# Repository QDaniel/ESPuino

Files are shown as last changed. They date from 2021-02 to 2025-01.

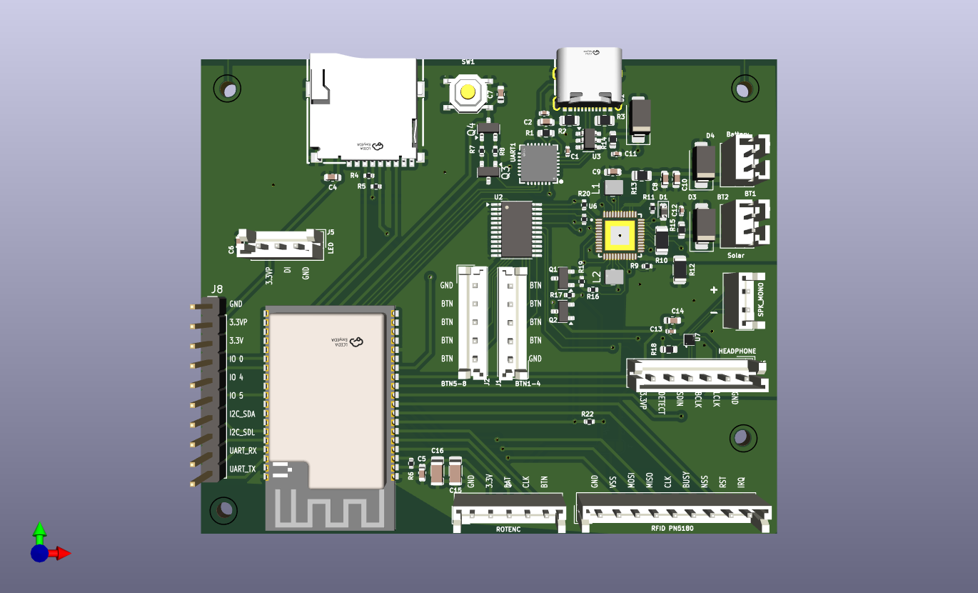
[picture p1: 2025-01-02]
PCBs/QUinoComplete/QUinoComplete_FG.png

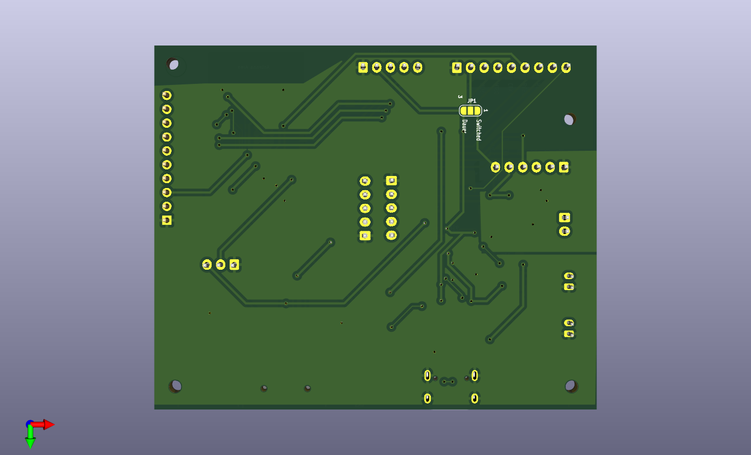
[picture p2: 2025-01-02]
PCBs/QUinoComplete/QUinoComplete_BG.png

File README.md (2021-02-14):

# ESPuino - rfid-based musiccontroller based on ESP32 with I2S-DAC-support

## NEWS
* As the creator of TonUINO claims it's trademark right, my project has been renamed to ESPuino. I'm totally respecting this and have to admit that I've been not aware of that. However, I instantly renamed everything and hopefully I didn't forget any parts. Since my repository has moved, please make sure (at least if you're using git) to change the URL of your local repository. An explanation was kindly [written by user](https://github.com/biologist79/ESPuino/issues/81).
* Please note: inline with the renaming of the project, MQTT-topics were changed as well as they've been including the old name. Please make sure to change your local MQTT-configuration as well. Sorry to [those](https://github.com/biologist79/ESPuino/issues/83) that spent time on this to point out.
* EN: I've set up a primarily German-speaking community with much documentation. Also an international corner for non-German-speakers is available at https://forum.espuino.de. Github-Login can be used there but it's not necessary.
* DE: Ich habe ein primär deutschsprachiges Forum aufgesetzt, welches ich mit reichlich Doku versehen habe. Würde mich freuen, euch dort zu sehen: https://forum.espuino.de. Ihr könnt euch dort mit eurem Github-Login einloggen, jedoch auch "normal" anmelden.
## Changelog
Moved to [another location](changelog.md) as it became to prominent here. Only last three events are kept:
* 01.02.2020: Introducing PCB: Lolin32 with SD_MMC + PN5180
* 06.02.2020: German umlauts now supported. When uploading via FTP make sure to change charset to CP437.
* 09.02.2020: Added support for bluetooth-sink (a2dp). Thanks @grch87 & @elmar-ops for providing this feature! Please note: wifi not available is now coloured green as blue make totally sense for bluetooth :-)
## Known bugs
* Some webstreams don't run. Guess it's a combination of saturated connection-pool and lack of heap-memory. Works probably better if ESP32-WROVER (e.g. Lolin D32 pro) is used, as this chip has PSRAM. Advice: Don't enable modules (e.g. MQTT) if you don't need them as this could save memory (and trouble).
* English translation for webgui is currently outdated. This will be fixed soon when i18n-support will be integrated.
## ESPuino - what's that?
The basic idea of ESPuino is to provide a way, to use the Arduino-platform for a music-control-concept that supports locally stored music-files without DRM-restrictions. This basically means that RFID-tags are used to direct a music-player. Even for kids this concept is simple: place an RFID-object (card, character) on top of a box and the music starts to play. Place another RFID-object on it and anything else is played. Simple as that.

The core of my implementation is based on the popular [ESP32 by Espressif](https://www.espressif.com/en/products/hardware/esp32/overview). Having WiFi-support out-of-the-box makes it possible to provide further features like an integrated FTP-server (to feed the player with music), smarthome-integration via MQTT, webradio and administration via webgui. However, my primary focus was to port the project to a modular base. Said this mp3-decoding is done in software with a dedicated uSD-card-slot and music-output is done via I2S-protocol. I did all my tests on [Adafruit's MAX98357A](https://learn.adafruit.com/adafruit-max98357-i2s-class-d-mono-amp/pinouts), [UDA1334](https://www.adafruit.com/product/3678) and [headphone-pcb](https://github.com/biologist79/ESPuino/tree/master/PCBs/Headphone%20with%20PCM5102a%20and%20TDA1308). Hopefully, not only in theory, other DACs that support I2S can be used as well.

## Hardware-setup
The heart of my project is an ESP32 on a [Wemos Lolin32 development-board](https://www.ebay.de/itm/4MB-Flash-WEMOS-Lolin32-V1-0-0-WIFI-Bluetooth-Card-Based-ESP-32-ESP-WROOM-32/162716855489). If ordered in China (Aliexpress, eBay e.g.) it's pretty cheap (around 4€) but even in Europe it's only around 8€. Make sure to install the drivers for the USB/Serial-chip (CP2102 e.g.). But probably it's better to use it's successor (which has battery-measurement already included): [Wemos Lolin D32](https://de.aliexpress.com/item/32808551116.html). Or, if you're planning to hear webstreams regularly, [Wemos Lolin D32 pro](https://de.aliexpress.com/item/32883116057.html) might be a good decision. It comes with uSD-slot onboard and because of its ESP32-WROVER-B has PSRAM included. PSRAM is used as webstream-cache and might be used more intensively in future.
* [MAX98357A (like Adafruit's)](https://de.aliexpress.com/item/32999952454.html)
* [uSD-card-reader; 3.3V only; supports SPI + SD-MMC](https://www.ebay.de/itm/Micro-SPI-Kartenleser-Card-Reader-2GB-SD-8GB-SDHC-Card-3-3V-ESP8266-Arduino-NEU/333796577968) or [cheaper](https://de.aliexpress.com/item/4000899753727.html)
* [RFID-reader RC-522](https://www.amazon.de/AZDelivery-Reader-Arduino-Raspberry-gratis/dp/B074S8MRQ7)
* [RFID-reader PN5180](https://de.aliexpress.com/item/4001278551831.html)
* [RFID-tags](https://www.amazon.de/AZDelivery-Keycard-56MHz-Schlüsselkarte-Karte/dp/B07TVJPTM7)
* [Neopixel-ring](https://de.aliexpress.com/item/32673883645.html)
* [Rotary Encoder](https://de.aliexpress.com/item/33041814942.html)
* [Buttons](https://de.aliexpress.com/item/32896285438.html)
* [Speaker](https://www.visaton.de/de/produkte/chassiszubehoer/breitband-systeme/fr-7-4-ohm)
* uSD-card: doesn't have to be a super-fast one; µC is limiting the throughput. Tested 32GB without any problems.
* uSD in SD-MMC (1 Bit) mode: Several devkits with onboard SD slot have support for this mode, e.g.: (https://de.aliexpress.com/item/4001229463219.html)
* optional replace the RFID-reader with a the better one: PN5180 comes with better RFID-range, less power-consumption and support for ISO-15693 / iCode SLIX2 tags (https://www.bing.com/shop?q=pn5180&FORM=SHOPTB)

## Getting Started
* Arduino-IDE can be used but you need to satisfy dependencies for all the libraries listed in `platformio.ini` manually.
* Instead I recommend to install Microsoft's [Visual Studio Code](https://code.visualstudio.com/). This is a popular and powerful IDE that gives you the ability to install tons of (well-supported) plugins.
* Install [Platformio Plugin](https://platformio.org/install/ide?install=vscode) into [Visual Studio Code](https://code.visualstudio.com/) and make sure to have a look at the [documentation](https://docs.platformio.org/en/latest/integration/ide/pioide.html). Step-by-step-manual is available [here](https://randomnerdtutorials.com/vs-code-platformio-ide-esp32-esp8266-arduino/.)
* Install [Git](https://git-scm.com/downloads) and make a copy ("clone") my repository to your local computer using `git clone https://github.com/biologist79/ESPuino.git`. Using git you can keep your local repository easily up to date without doing copy'n'paste. To keep it up to date run `git pull origin master`. Further infos [here}(https://stackoverflow.com/questions/1443210/updating-a-local-repository-with-changes-from-a-github-repository).
* (Optional) Install [Gitlens](https://marketplace.visualstudio.com/items?itemName=eamodio.gitlens) as plugin (to have advanced Git-support).
* Now, that the git-repository is saved locally, import this folder into Platformio as a project.
* There's a file called `platformio.ini`, that contains the configuration for different develboards (e.g. env:lolin32). Platformio supports hundrets of boards out of the box. So probably you need to change/extend that configuration. Guess Lolin32 is described in platformio.ini but you need Lolin D32, then lookup Platformio's [documentation](https://docs.platformio.org/en/latest/boards/espressif32/lolin_d32.html) to know what to change.
* Depending on your operating system (Windows, Mac OS, Linux), you probably need to change `upload_port`and `monitor_port` as well.
* Edit `src/settings.h` according your needs. Especially don't forget to set `HAL` depending on your develboard.
* Edit board-specific (`HAL`) config-file (e.g. `settings-lolin32.h` for Lolin32 or `settings-lolin_d32.h` for Lolin D32). If you're running a board that is not listed there: start with `settings-custom.h` and change it according your needs.
* Connect your develboard via USB, click the alien-head to the left and run `Upload and Monitor`. All libraries necessary should be fetched in background now followed by code-compilation. After that, your ESP32 is flashed with the firmware. Depending on your develboard it might me necessary to push a button in order to allow ESP32 to enter flashmode (not necessary für Lolin32, D32 und D32 pro).
* Now have a look at the serial-output at the bottom of Visual Studio Code's windows. At the first run there might appear a few error-messages (related to missing entries in NVS). Don't worry, this is just normal. However, make sure SD is running as this is mandatory!
* If everything ran fine, at the first run, ESPuino should open an access-point with the name "ESPuino". Join this WiFi with your computer (or mobile) and enter `192.168.4.1` to your webbrowser. Enter WiFi-credentials and the hostname. After saving the configuraton, restart ESPuino. Hint: I tried to connect this access-point via Android mobile. Basically that's no problem, but as my mobile detected there'd be no internet-connection, it keept LTE-connection open and prevented me from connecting to `192.168.4.1`. So if in doubts use a computer.
* After reboot ESPuino tries to join your WiFi (with the credentials previously entered). If that was successful, an IP is shown in the serial-console of Visual Studio Code. You can call ESPuino's GUI using a webbrowser via this IP; make sure to allow Javascript. If mDNS-feature is active in `src/settings.h`, you can use the hostname configured extended by .local instead the IP. So if you configured `espuino` as hostname, you can use `espuino.local` for webgui and FTP.
* Via FTP you can upload data (but don't expect it to be super fast). It's round about 185 kb/s if SD is in SPI-mode and 310 kB/s if SD is in MMC-mode.
* FTP needs to be activated after boot by pressing `PAUSE` + `NEXT`-buttons (in parallel) first! Neopixel flashes green (1x) if enabling was successful. It'll be disabled automatically after next reboot. Means: you have to enable it every time you need it (if reboot was in between). Sounds annoying and maybe it is, but's running this way in order to have more heap-memory available (for webstream) if FTP isn't running.
* Via webbrowser you can configure various settings and pair RFID-tags with actions. If MQTT/FTP-support was not compiled, their config-tabs won't appear.

## Prerequisites / tipps
* Open settings.h
* choose if optional modules (e.g. MQTT, FTP, Neopixel) should be compiled/enabled
* For debugging-purposes serialDebug can be set to ERROR, NOTICE, INFO or DEBUG.
* If MQTT=yes, set the IP or hostname of the MQTT-server accordingly and check the MQTT-topics (states and commands)
* Advice: don't enable MQTT if there's no broker around because network-timeouts can really be a PITA.
* If Neopixel enabled: set NUM_LEDS to the LED-number of your Neopixel-ring and define the Neopixel-type using `#define CHIPSET`
* If you're using Arduino-IDE please make sure to change ESP32's partition-layout to `No OTA (2MB APP/2MB Spiffs)` as otherwise the sketch won't fit into the flash-memory.
* Open board-specific config-file and edit according your needs.
* If you want to monitor battery's voltage, make sure to enable `MEASURE_BATTERY_VOLTAGE`. Use a voltage-divider as voltage of a LiPo is way too high for ESP32 (only 3.3V supported!). For my tests I connected VBat with a serial connection of 130k + 130k resistors (VBat(+)--130k--X--130k--VBat(-)). X is the measure-point where to connect the GPIO to. If using Lolin D32 or Lolin D32 pro, make sure to leave both resistor-values unchanged at 100k. Same for GPIO: unchanged at 35.
Please note: via GUI upper and lower voltage cut-offs for visualisation of battery-voltage (Neopixel) is available. Additional GUI-configurable values are interval (in minutes) for checking battery voltage and the cut off-voltage below whose a warning is shown via Neopixel.
* If you're using a headphone-pcb with a [headphone jack](https://www.conrad.de/de/p/cliff-fcr1295-klinken-steckverbinder-3-5-mm-buchse-einbau-horizontal-polzahl-3-stereo-schwarz-1-st-705830.html) that has a pin to indicate if there's a plug, you can use this signal along with the feature `HEADPHONE_ADJUST_ENABLE` to limit the maximum headphone-voltage automatically. As per default you have to invert this signal (with a P-channel MOSFET) and connect it to GPIO22.
* Enabling `SHUTDOWN_IF_SD_BOOT_FAILS` is really recommended if you run your ESPuino in battery-mode without having a restart-button exposed to the outside of ESPuino's enclosure. Because otherwise there's no way to restart your ESPuino and the error-state will remain until battery is empty (or you open the enclosure, hehe).
* Enabling `PLAY_LAST_RFID_AFTER_REBOOT` will tell ESPuino to remember the last RFID-tag played after next reboot. So rebooting ESPuino will end up in autoplay. I don't really recommend this feature because if you use it along with a webstream, in case of streaming-issues this might end up in an infinite loop.

## SD-card: SPI or SD-MMC (1 bit)-mode?
Having SD working is mandatory. However, there are two modes available to access SD-cards: SPI and SD-MMC (1 bit).<br />
Advantages SD-MMC (1 bit) over SPI:
* Needs only three GPIOs (instead of four)
* It's faster. FTP-upload: 298 kiB vs 178 kiB. HTTP-upload: 372 kiB vs 184 kiB. (tested with filesize of 70.7 MiB.<br />
So why using SPI if SD-MMC seems to be better? The primary problem of SD-MMC is: you cannot choose different GPIOs. That doesn't sound bad but this can (depending on the uSD-card-reader-module) be a problem because maybe GPIO2 is pulled HIGH to 3.3V by a 10k-resistor. For example this is the case when using the reader-module named above in hardware-setup. It's a problem because if GPIO2 is pulled high at boot, ESP32 doesn't enter flash-mode. As soon as flash-mode is entered, it's no longer a problem. However, this behaviour can be an issue if ESP32 is deeply "burried" in ESPuino's enclosure and you want to update its firmware. But fortunately there's a way to bypass this problem: remove the [pullup-resistor shown in the picture](https://raw.githubusercontent.com/biologist79/ESPuino/master/pictures/Pullup-removal.jpg). It can be removed safely because if MMC-mode is set, pullup is done in software using `pinMode(2, INPUT_PULLUP);`. So it's not really a problem but you have to take note of that!

## RFID: RC522 or PN5180?
RC522 is so to say the Tonuino-standard. It's cheap and works, but RFID-tag has to be placed near the reader. PN5180 instead has better RFID range/sensitivity and can read ISO-15693 / iCode SLIX2-tags aka 'Tonies' (you need a password to read Tonies). You can also wake-up the board with the card. Disadvantages: is a bit more expensive and needs more GPIOs (6/7 instead of 4). Refer PN5180's wire-section below for further informations. Hint: if using 3.3V make sure to connect PN5180 to +5V AND 3.3V. Sounds weird but it's necessary.

## 3.3 or 5V?
* Why 3.3V? Because: if you plan to use battery-mode with a LiPo, there's no 5 V available (unless USB is connected).
That's why my design's focus is 3.3 V. If you want to use 5 V - do so, but be advised it's not compatible with LiPo-battery-mode. The Mosfet-circuit for saving power in deepsleep (see [Lolin32-schematics](https://github.com/biologist79/ESPuino/blob/master/PCBs/Wemos%20Lolin32/Pictures/Tonuino%20V2-Schematics.pdf) as reference) works as well for 5 V.
* MAX98357a: provides more power at 5 V but also runs at 3.3 V. Anyway: it's still loud enough (in my opinion).
* Neopixel: specification says it needs 5 V but also runs at 3.3 V.
* RC522: needs 3.3 V (don't power with 5 V!)
* PN5180: at 3.3 V make sure to connect both 5 V and 3.3 V-pins to 3.3 V.
* SD: needs 3.3 V but if voltage-regulator is onboard, it can be connected to 5 V as well
* Rotary encoder: 3.3 V (don't power with 5 V! Encoder doens't care if connected to 3.3 or 5 V, but GPIOs of ESP32 do!)

## Wiring (general)
Depending on the develboard you're using and the needs you have, there are different options available.
A lot of wiring is necessary to get ESPuino working. After my first experiments on a breadboard I soldered all the stuff onto a PCB in order to avoid wild-west-cabling. Especially for the interconnect between µC and uSD-card-reader make sure to use short wires (like 10cm or so)! As of my experience with a breadbord, male/male-connectors are better than female/female-connectors. Important: you can easily connect another I2S-DACs by just connecting them in parallel to the I2S-pins (DIN, BCLK, LRC). This is true for example if you plan to integrate a [line/headphone-pcb](https://www.adafruit.com/product/3678). In general, this runs fine. But unfortunately especially this board lacks of a headphone jack, that takes note if a plug is inserted or not. Best way is to use a [headphone jack](https://www.conrad.de/de/p/cliff-fcr1295-klinken-steckverbinder-3-5-mm-buchse-einbau-horizontal-polzahl-3-stereo-schwarz-1-st-705830.html) that has a pin that is pulled to GND, if there's no plug and vice versa. Using for example a MOSFET-circuit, this GND-signal can be inverted in a way, that MAX98357.SD is pulled down to GND if there's a plug. Doing that will mute MAX98537a and so turn off the speaker immediately if there's a plug and vice versa. Have a look at the PCB-folder in order to view the detailed solution. Here's an example for such a [headphone-pcb](https://github.com/biologist79/ESPuino/tree/master/PCBs/Headphone%20with%20PCM5102a%20and%20TDA1308) that makes use of GND.<br />
Have a look at the PCB-folder. I provided PCBs for a number of develboards. Probably this makes things easier for you.

## Wiring (2 SPI-instances: RC522 + SD)
Uses two SPI-instances. The first one for the RFID-reader and the second for SD-card-reader. This is also the [setup, I personally use](https://github.com/biologist79/ESPuino/tree/master/PCBs/Wemos%20Lolin32).<br />
| ESP32 (GPIO)  | Hardware | Pin | Comment |
| --- | --- | --- | --- |
| 3.3 (5) V | SD-reader | VCC | Connect to p-channel MOSFET for power-saving when µC is off  |
| GND | SD-reader | GND | |
| 15 | SD-reader | CS | |
| 13 | SD-reader | MOSI | |
| 16 | SD-reader | MISO | |
| 14 | SD-reader | SCK | |
| 3.3 V | RFID-reader | 3.3V | (Connect directly to GPIO 17 for power-saving when µC is off)  |
| GND | RFID-reader | GND | |
| 21 | RFID-reader | CS/SDA | |
| 23 | RFID-reader | MOSI | |
| 19 | RFID-reader | MISO | |
| 18 | RFID-reader | SCK | |
| 5 / 3.3 V | MAX98357 | VIN | Connect to p-channel MOSFET for power-saving when µC is off  |
| GND | MAX98357 | GND | |
| 25 | MAX98357 | DIN | |
| 27 | MAX98357 | BCLK | |
| 26 | MAX98357 | LRC | |
| --- | MAX98357 | SD | Info: if pulled down to GND amp will turn off |
| 34 | Rotary encoder | CLK | Change CLK with DT if you want to change the direction of RE |
| 35 | Rotary encoder | DT | Change CLK with DT if you want to change the direction of RE |
| 32 | Rotary encoder | BUTTON | |
| 3.3 V | Rotary encoder | + | |
| GND | Rotary encoder | GND | |
| 4 | Button (next) | | |
| GND | Button (next) | | |
| 2 | Button (previous) | | |
| GND | Button (previous) | | |
| 5 | Button (pause/play) | | |
| GND | Button (pause/play) | | |
| 3.3 V | Neopixel | V | Connect to p-channel MOSFET for power-saving when µC is off  |
| GND | Neopixel | G | |
| 12 | Neopixel | DI | |
| 17 | N-channel Mosfet | Gate | |
| 33 | Voltage-divider / BAT | | Optional: voltage-divider to monitor battery-voltage |
| 22 | Headphone jack | | Optional: if pulled to ground, headphone-volume is set |

Optionally, GPIO 17 can be used to drive a Mosfet-circuit in order to switch off peripherals (SD, Neopixel, RFID and MAX98357a) if ESP32 is in deepsleep. Please refer the schematics for my [Lolin32-PCB](https://github.com/biologist79/ESPuino/blob/master/PCBs/Wemos%20Lolin32/Pictures/Tonuino-Lolin32-Schematics.pdf) for further informations. If you need further informations on transistor-circuits visit this [website](https://dl6gl.de/schalten-mit-transistoren.html). <br />
In general I recommend using a [uSD-card-reader](https://www.ebay.de/itm/Micro-SPI-Kartenleser-Card-Reader-2GB-SD-8GB-SDHC-Card-3-3V-ESP8266-Arduino-NEU/333796577968) that can be run solely with 3.3V (doesn't have a voltage-regulator). This is because if 3.3V go through the voltage regulator a small voltage-drop will be introduced, which may lead to SD-malfunction as the resulting voltage is a bit too low. Vice versa if you want to connect your reader solely to 5V, make sure to have one WITH a voltage regulator :-). And by the way: when LiPo-battery is connected, there's no 5V. That's why I designed my [Lolin-PCBs](https://github.com/biologist79/ESPuino/tree/master/PCBs/Wemos%20Lolin32) with 3.3V only.

## Wiring (SD-card in 1 Bit SD-MMC mode) different to above
| ESP32 (GPIO)  | Hardware | Pin | Comment |
| --- | --- | --- | --- |
| -- | SD-reader | CS | no CS required |
| 15 | SD-reader | MOSI | |
| 2 | SD-reader | MISO | make sure there's no [hardware-pullup](https://raw.githubusercontent.com/biologist79/ESPuino/master/pictures/Pullup-removal.jpg) for MISO |
| 14 | SD-reader | SCK | |

Make sure to enable `SD_MMC_1BIT_MODE` if you want to use this feature. Don't(!) enable `SINGLE_SPI_ENABLE`. SD-MMC-mode requires these fixed PINs listed above. You can find a good comparison of different SD-card-modes here: (https://www.instructables.com/Select-SD-Interface-for-ESP32/).
Advice: Double check that above PINs are not used elsewhere (e.g. GPIO2 is used as PREVIOUS_BUTTON as per default in settings.h).

## Wiring (1 SPI-instance: RC522 + SD) [EXPERIMENTAL, maybe not working!]
Basically the same as using 2 SPI-instances but...
In this case RFID-reader + SD-reader share SPI's SCK, MISO and MOSI. But make sure to use different CS-pins. Have to admit I had some problems to get this running. Seems to be connected properly, but nothing happens when an RFID-tag is applied. Maybe anybody else wants to point out :-)

| ESP32 (GPIO)  | Hardware | Pin | Comment |
| --- | --- | --- | --- |
| 3.3 (5) V | SD-reader | VCC | Connect to p-channel MOSFET for power-saving when µC is off  |
| GND | SD-reader | GND | |
| 15 | SD-reader | CS | Don't share with RFID! |
| 3.3 V | RFID-reader | 3.3V | Connect directly to GPIO 17 for power-saving when µC is off  |
| GND | RFID-reader | GND | |
| 21 | RFID-reader | CS/SDA | Don't share with SD! |
| 23 | RFID+SD-reader | MOSI | |
| 19 | RFID+SD-reader | MISO | |
| 18 | RFID+SD-reader | SCK | |
| 5 / 3.3 V | MAX98357 | VIN | Connect to p-channel MOSFET for power-saving when µC is off  |
| GND | MAX98357 | GND | |
| 25 | MAX98357 | DIN | |
| 27 | MAX98357 | BCLK | |
| 26 | MAX98357 | LRC | |
| --- | MAX98357 | SD | Info: if pulled down to GND amp will turn off |
| 34 | Rotary encoder | CLK | Change CLK with DT if you want to change the direction of RE |
| 35 | Rotary encoder | DT | Change CLK with DT if you want to change the direction of RE |
| 32 | Rotary encoder | BUTTON | |
| 3.3 V | Rotary encoder | + | |
| GND | Rotary encoder | GND | |
| 4 | Button (next) | | |
| GND | Button (next) | | |
| 2 | Button (previous) | | |
| GND | Button (previous) | | |
| 5 | Button (pause/play) | | |
| GND | Button (pause/play) | | |
| 5 / 3.3 V | Neopixel | V | Connect to p-channel MOSFET for power-saving when µC is off  |
| GND | Neopixel | G | |
| 12 | Neopixel | DI | |
| 17 | N-channel Mosfet | Gate | |
| 33 | Voltage-divider / BAT | | Optional: voltage-divider to monitor battery-voltage |
| 22 | Headphone jack | | Optional: if pulled to ground, headphone-volume is set |

## Wiring (PN5180 instead of MFRC522) different to above
PN5180-reader needs at least two more GPIOs: RESET and BUSY. Double check pin-conflicts! `RFID_READER_TYPE_PN5180` needs to be enabled to use this feature. Make sure to disable `RFID_READER_TYPE_MFRC522` if doing so!
You can enable low power card-detection with `PN5180_ENABLE_LPCD`, but this needs another GPIO for IRQ. With low power card detection (LPCD) you can wake-up the ESP32 from deep-sleep just by applying a card to the reader. You need a PN5180-firmware >= 4.0. Most china-boards comes with older firmware. The latest firmware can be flashed with this [project](https://github.com/abidxraihan/PN5180_Updater_ESP32).

| ESP32 (GPIO)  | Hardware | Pin | Comment |
| --- | --- | --- | --- |
| 3.3 V | PN5180 RFID-reader | 3.3V | Connect directly to GPIO 17 for power-saving when µC is off |
| 3.3 V | | 3.3V | For low power card detection mode (LPCD) connect directly to 3.3V |
| 5 / 3.3 V | PN5180 RFID-reader | 5V | Don't forget to connect this pin the same way as 3.3V |
| GND | PN5180 RFID-reader | GND | |
| 21 | PN5180 RFID-reader | CS/SDA | Same as MFRC522. Don't share with SD! |
| 23 | PN5180 RFID-reader | MOSI | Same as MFRC522 |
| 19 | PN5180 RFID-reader | MISO | Same as MFRC522 |
| 18 | PN5180 RFID-reader | SCK | Same as MFRC522 |
| 16 | PN5180 RFID-reader | BUSY | be aware of SD MISO if running in SPI mode |
| 22 | PN5180 RFID-reader | RST | be aware of Headphone jack PIN |
| 39 | PN5180 RFID-reader | IRQ | optional, used for low power card detection (LPCD) |

## Wiring (custom) / different pinout
When using a develboard with SD-card-reader already integrated (Lolin D32 Pro, several TTGO-boards), the pinouts described above my not fit. Feel free to change them according your needs. Additionaly some boards may use one or some of the GPIOs I used for their internal purposes and that reason for are maybe not exposed via pin-headers. However, having them exposed doesn't mean they can be used without limits. This is because some GPIOs have to be logical LOW or HIGH at start/boot for example and this is probably not the case when connecting stuff to it. Feel free to adjust the GPIOs proposed by me (but be adviced it could take a while to get it running). If you encounter problems please refer the board's manual first. <br />
[Here](https://github.com/biologist79/ESPuino/tree/master/Hardware-Plaforms/ESP32-A1S-Audiokit) I described a solution for a board with many GPIOs used internally and a very limited number of GPIOs exposed. That's why I had to use different SPI-GPIOs for RFID as well. Please note I used a slightly modified [RFID-lib](https://github.com/biologist79/ESPuino/tree/master/Hardware-Plaforms/ESP32-A1S-Audiokit/lib/MFRC522) there. Please note: the code-basis is outdated. Will need to re-integrate it into my master-branch...

## WiFi
WiFi is mandatory for webgui, FTP and MQTT. However, WiFi can be temporarily or permanently disabled. There are two ways to do that:
* Use a special modification-card that can be configured via webgui
* Press previous-key (and keep it pressed) + press next-button in parallel shortly. Now release both.
This toggles the current WiFi-status: if it's currently enabled, it will be disabled instantly and vice versa. Please note: this WiFi-status will remain until you change it again, which means, that ESPuino will remember this state after the next reboot. Having Wifi enabled is indicated in idle-mode (no playlist active) with four *white* slow rotating LEDs whereas disabled WiFi is represented by those ones coloured *green*. Bluetooth-mode is indicated by *blue* LEDs.

## Bluetooth
ESPuino can be used as bluetooth-sink (a2dp). This mode can be enabled/disabled via a RFID-modification-card. Applying one will restart ESPuino immediately. Two modes are available which are toggled in between: "normal" and "bluetooth". Normal means: SD + WiFi are available whereas in mode "bluetooth" only bluetooth-support can be provided. If bluetooth is active, this is indicated by four slow rotating *blue* LEDs. Now you can stream to your ESPuino e.g. with your mobile device. Tested this with Android 8 and worked 100% flawless.
## After ESPuino is connected to your WiFi
After bringing ESPuino part of your LAN/WiFi, the 'regular' webgui is available at the IP assigned by your router (or the configured hostname). Using this GUI, you can configure:
* WiFi
* Binding between RFID-tag, file/directory/URL and playMode
* Binding between RFID-tag and a modification-type
* MQTT
* FTP
* Initial volume, maximum volume (speaker / headphone), brightness of Neopixel (nightmode / default) and inactivity-time

Webgui #1:


Webgui #2:


Webgui #3:


Webgui #4:


Webgui #5:


Webgui #6:


Webgui #7:


Webgui: websocket broken:


Webgui: action ok:


Please note: as you apply a RFID-tag to the RFID-reader, the corresponding ID is pushed to the GUI. So there's no need to enter such IDs manually (unless you want to). Filepath can be filled out by selecting a file/directory in the tree.
IMPORTANT: Every time you add, delete or rename stuff on the SD-card, it's necessary to rebuild the json-indexfile. Simply click on the refresh-button below the filetree and wait until it's done. This is because all operations of the filebrowser rely on this file in order to provide a fast way to access all the files and directories.

## Interacting with ESPuino
### Playmodes
It's not just simply playing music; different playmodes are supported:
* `single track` => plays one track one time
* `single track (loop)` => plays one track forever
* `audiobook `=> single file or playlist/folder; last play-position (file and playlist) is saved (when pushing pause or moving to another track) and re-used next time
* `audiobook` (loop) => same as audiobook but loops forever
* `folder/playlist (alph. sorted)` => plays all tracks in alph. order from a folder one time
* `folder/playlist (random order)` => plays all tracks in random order from a folder one time
* `folder/playlist (alph. sorted)` => plays all tracks in alph. order from a folder forever
* `folder/playlist (random order)` => plays all tracks in random order from a folder forever
* `webradio` => always only one "track": plays a webstream

### Modification RFID-tags
There are special RFID-tags, that don't start music by themself but can modify things. If applied a second time, it's previous action/modification will be reversed. Please note: all sleep-modes do dimming (Neopixel) automatically because it's supposed to be used in the evening when going to bed. Well, at least that's my children's indication :-) So first make sure to start the music then use a modification-card in order to apply your desired modification:
* lock/unlock all buttons
* sleep after 5/30/60/120 minutes
* sleep after end of current track
* sleep after end of playlist
* sleep after five tracks
* dimm neopixel
* current track in loop-mode (is "stronger" than playlist-loop but doesn't overwrite it!)
* playlist in loop-mode
* track und playlist loop-mode can both be activated at the same time, but unless track-loop isn't deactivated, playlist-loop won't be effective
* Toggle WiFi (enable/disable) => disabling WiFi while webstream is active will stop the webstream instantly!
* Toggle Bluetooth (enable/disable) => restarts ESPuino immediately

### Neopixel-ring (optional)
Indicates different things. Don't forget configuration of number of LEDs via #define NUM_LEDS
* While booting: every second LED (rotating orange)
* Unable to mount SD: LEDs flashing red (will remain forever unless SD-card is available or `SHUTDOWN_IF_SD_BOOT_FAILS` is active)
* IDLE: four LEDs slow rotating (white if WiFi enabled; green if WiFi disabled)
* BLUETOOTH: four LEDs slow rotating coloured blue
* ERROR: all LEDs flashing red (1x) if an action was not accepted
* OK: all LEDs flashing green (1x) if an action was accepted
* BUSY: violet; four fast rotating LEDs when generating a playlist. Duration depends on the number of files in your playlist.
* track-progress: rainbow; number of LEDs relative to play-progress
* playlist-progress: blue; appears only shortly in playlist-mode with the beginning every new track; number of LEDs relative to progress
* webstream: two slow rotating LEDs that change their colours rainbow-wise as the stream proceeds
* volume: green => red-gradient; number of LEDs relative from current to max volume
* switching off: red-circle that grows until long-press-time is reached
* buttons locked: track-progress-LEDs coloured red
* paused: track-progress-LEDs coloured orange
* rewind: if single-track-loop is activated a LED-rewind is performed when restarting the given track
* (Optional) Undervoltage: flashes three times red if battery-voltage is too low. This voltage-level can be configured via GUI.
* (Optional) Short press of rotary encoder's button provides battery-voltage visualisation via Neopixel. Upper und lower voltage cut-offs can be adjusted via GUI. So for example if lower voltage is set to 3.2 V and upper voltage to 4.2 V, 50% of the LEDs indicate a voltage of 3.7 V.

Please note: some Neopixels use a reversed addressing which leads to the 'problem', that all effects are shown
counter clockwise. If you want to change that behaviour, just enable `NEOPIXEL_REVERSE_ROTATION`.

### Buttons
Some buttons have different actions if pressed long or short. Minimum duration for long press in ms is defined by `intervalToLongPress`.
* previous (short): previous track / beginning of the first track if pressed while first track is playing
* previous (long): first track of playlist
* next (short): next track of playlist
* next (long): last track of playlist
* pause/play (short/long): pause/play
* rotary encoder (turning): vol +/-
* rotary encoder (button long): switch off (only when on)
* rotary encoder (button short): switch on (when switched off)
* rotary encoder (button short): show battery-voltage via Neopixel (when switched on and `MEASURE_BATTERY_VOLTAGE` is active)
* previous (long; keep pressed) + next (short) + release (both): toggle WiFi enabled/disabled

### Music-play
* Music starts to play right after a valid RFID-tag was applied
* If `PLAY_LAST_RFID_AFTER_REBOOT` is active, ESPuino will remember the last RFID applied => music-autoplay (if in doubts don't use this feature).
* If a folder should be played that contains many mp3s, the playlist generation can take a few seconds. Please note that a file's name including path cannot exceed 255 characters.
* While playlist is generated Neopixel indicates BUSY-mode.
* After last track was played, Neopixel indicates IDLE-mode.
* In audiobook-mode, last play-position is remembered (position in actual file and number of track, respectively) when a new track begins of if pause-button was hit.
* In webstream-mode the stream will instantly stop if WiFi-status is toggled to disabled. ESPuino will return to idle-mode and wait for new RFID-tag.

### Audiobook-mode
This mode is different from the other ones because the last playposition is saved. Playposition is saved when...
* next track starts.
* first/previous/last track requested by button.
* pause was pressed.
* playlist is over (playposition is set back to the first track and file-position 0).
* Please note: last playposition is not saved when applying a new RFID-tag. This is intended because otherwise you woldn't have a possibility to not save it.

### Webinterface-configuration
After having ESPuino running on your ESP32 in your local WiFi, the webinterface-configuration is accessable. Using this GUI you can configure:
* Wifi-configuration (Wifi-SSID, Wifi-password, ESPuino's name (for nameserver))
* Link between RFID-tag and corresponding action
* (optional) MQTT-configuration (broker's IP)
* (optional) FTP-configuration (username and password)
* General-configuration (volume (speaker + headphone), neopixel-brightness (night-mode + initial), sleep after inactivity)

### FTP (optional)
* FTP needs to be activated after boot by pressing `PAUSE` + `NEXT`-buttons (in parallel) first! Neopixel flashes green (1x) if enabling was successful. It'll be disabled automatically after next reboot. Means: you have to enable it every time you need it (if reboot was in between). Sounds annoying and maybe it is, but's running this way in order to have more heap-memory available (for webstream) if FTP isn't running.
* In order to avoid exposing uSD-card or disassembling ESPuino all the time for adding new music, it's possible to transfer music to the uSD-card using FTP.
* Default-user and password are set to `esp32` / `esp32` but can be changed later via GUI.
* Make sure to set the max. number of parallel connections to ONE in your FTP-client and the charset to CP437. CP437 is important if you want to use german umlauts (öäüß).
* Secured FTP is not available. So make sure to disable SSL/TLS.
* Software: my recommendation is [Filezilla](https://filezilla-project.org/) as it's free and available for multiple platforms.
* Don't expect a super fast data-transfer; it's around 185 kB/s (SPI-mode) and 310 kB/s (MMC-mode).
* Please note: if music is played in parallel, this rate decrases dramatically! So better stop playback when doing a FTP-transfer.

### Energy saving
As already described in the modify-section, there are different sleepmodes available. Additionaly µC will be put into deepsleep after 10 minutes of inactivity (configurable my maxInactivityTime) unless ESPuino doesn't play music, has a FTP-client connected and any input via buttons. Every button-interaction resets the counter.

### MQTT (optional)
Everything that can be controlled via RFID-tags and buttons, can also be controlled via MQTT (excepting toggling WiFi-status as this doesn't make sense). All manual interactions (buttons, RFID-tags) are also sent to MQTT in parallel, so everything is always in-sync (unless Wifi/MQTT-connection is broken). In my home-setup I'm using [openHAB](https://www.openhab.org/) to "encapsulate" MQTT into a nice GUI, that's accessible via APP + web. I [described](https://github.com/biologist79/ESPuino/tree/master/openHAB) a sample-config for openHAB2. However, meanwhile openHAb3 is available and all the stuff described can also be configured via GUI. Be advised that openHAB is pretty complex and you have to spend some time to get familiar with it.

### Supported file/stream-types
Please refer [ESP32-audioI2S](https://github.com/schreibfaul1/ESP32-audioI2S), as this is the library I used for music-decoding. Make sure to update especially this library regularly as it's development is still in progress.

### Backups
As all assignments between RFID-IDs and actions (playmode, file to play...) is saved in ESP's NVS, the problem is that it's all gone when the ESP is broken. So that's where a backup comes into play. So every time you change or add a new assignment between a RFID-tag and an action via GUI, a backup-file is saved on the uSD-card. The file's name can be changed via `backupFile`. So better don't delete it! Using the webgui you can use the upload-form to import such a file. To be honest: Sometimes I had some issues with Firefox doing this whereas Safari turned out to do it right. Don't know why :-(.

## Smarthome (optional)
As already described, MQTT is supported. In order to use it it's necessary to run a MQTT-broker; [Mosquitto](https://mosquitto.org/) for instance. After connecting to it, ESPuino subscribes to all command-topics. State-topics are used to push states to the broker in order to inform others if anything changed (change of volume, new playlist, new track... name it). Others, like openHAB, subscribe to state-topics end send commands via command-topics. So it's not just limited to openHAB. It's just necessary to use a platform, that supports MQTT. For further informations (and pictures) refer the [subfolder](https://github.com/biologist79/ESPuino/tree/master/openHAB).

## MQTT-topics and their ranges
Feel free to use your own smarthome-environments (instead of openHAB). The MQTT-topics available are described as follows. Please note: if you want to send a command to ESPuino, you have to use a cmnd-topic whereas ESPuino pushes its states back via state-topics. So guess you want to change the volume to 8 you have to send this number via topic-variable `topicLoudnessCmnd`. Immediately after doing to, ESPuino sends a conformation of this command using `topicLoudnessState`. To get hands on MQTT I recommend this [one](https://www.hivemq.com/mqtt-essentials/) as introducton (covers more than you need for ESPuino).

| topic-variable | range | meaning |
| --- | --- | --- |
| topicSleepCmnd | 0 or OFF | Power off ESPuino immediately |
| topicSleepState | ON or OFF | Sends ESPuino's current/last state |
| topicRfidCmnd | 12 digits | Set number of RFID-tag which 'emulates' an RFID-tag (e.g. `123789456089`) |
| topicRfidState | 12 digits | ID of current RFID-tag (if not a modification-card) |
| topicTrackState | String | Sends current track number, total number of tracks and full path of curren track. E.g. "(2/10) /mp3/kinderlieder/Ri ra rutsch.mp3" |
| topicTrackControlCmnd | 1 -> 7 | `1`=stop; `2`=unused!; `3`=play/pause; `4`=next; `5`=prev; `6`=first; `7`=last |
| topicLoudnessCmnd | 0 -> 21 | Set loudness (depends on minVolume / maxVolume) |
| topicLoudnessState | 0 -> 21 | Sends loudness (depends on minVolume / maxVolume |
| topicSleepTimerCmnd | EOP | Power off after end to playlist |
| | EOT | Power off after end of track |
| | EO5T | Power off after end of five tracks |
| | 1 -> 2^32 | Duration in minutes to power off |
| | 0 | Deactivate timer (if active) |
| topicSleepTimerState | various | Sends active timer (`EOP`, `EOT`, `EO5T`, `0`, ...) |
| topicState | Online, Offline | `Online` when powering on, `Offline` when powering off |
| topicCurrentIPv4IP | IPv4-string | Sends ESPuino's IP-address (e.g. `192.168.2.78`) |
| topicLockControlsCmnd | ON, OFF | Set if controls (buttons, rotary encoder) should be locked |
| topicLockControlsState  | ON, OFF | Sends if controls (buttons, rotary encoder) are locked |
| topicPlaymodeState | 0 - 10 | Sends current playmode (single track, audiobook...; see playmodes) |
| topicRepeatModeCmnd | 0 - 3 | Set repeat-mode: `0`=no; `1`=track; `2`=playlist; `3`=both |
| topicRepeatModeState | 0 - 3 | Sends repeat-mode |
| topicLedBrightnessCmnd  | 0 - 255 | Set brightness of Neopixel |
| topicLedBrightnessState | 0 - 255 | Sends brightness of Neopixel |
| topicBatteryVoltage | float | Voltage (e.g. 3.81) |

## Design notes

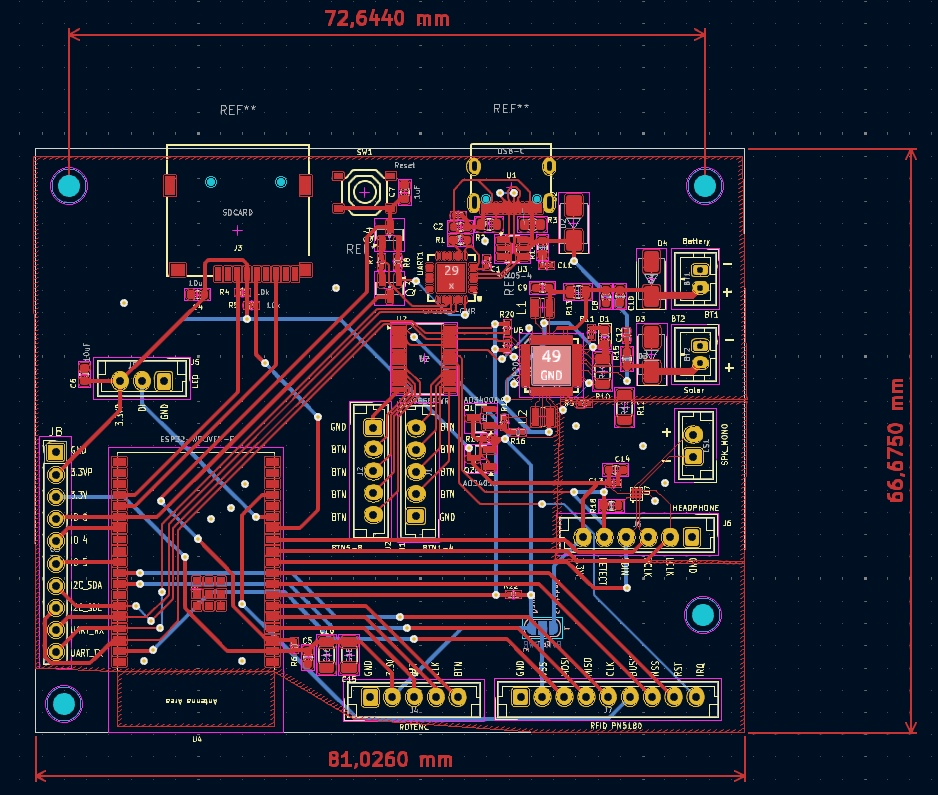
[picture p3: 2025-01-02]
PCBs/QUinoComplete/QUinoComplete_PL.png

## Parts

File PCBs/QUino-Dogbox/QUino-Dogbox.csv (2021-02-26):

Comment | Designator | Footprint | LCSC Part #
DW02S | BAT1 | JST_PH_B2B-PH-K_1x02_P2.00mm_Vertical
10uF/C0603 | C1 | C_0603_1608Metric_Pad1.08x0.95mm_HandSolder | C19702
27pF/50V/5%/C0G/C0402 | C2,C3 | C_0402_1005Metric_Pad0.74x0.62mm_HandSolder | C1555
22uF/6.3V/20%/X5R/C0603 | C4,C7,C9 | C_0603_1608Metric_Pad1.08x0.95mm_HandSolder | C59461
100nF/10V/10%/X7R/C0402 | C5,C6,C10 | C_0402_1005Metric_Pad0.74x0.62mm_HandSolder | C1525
1uF/10V/10%/X5R/C0402 | C8 | C_0402_1005Metric_Pad0.74x0.62mm_HandSolder | C52923
1N5819W/SOD123 | D1,D2,D3,D4,D6,D7,D8,D9 | D_SOD-123 | C402219
BAT54C(SOT23-3) | D5 | SOT-23_Handsoldering | C375703
WPM2015-3/TR | FET1 | SOT-23_Handsoldering | C213159
TP5000-QFN16 | IC1 | QFN65P400X400X90-17N-D | C51699
4.7u Inductor | L1 | L_1206_3216Metric | C1049
Q12MHz/20pF/10ppm/4P/3.2x2.5mm | Q1 | Crystal_SMD_3225-4Pin_3.2x2.5mm_HandSoldering | C9002
BC817-40(SOT23) | Q2,Q3 | SOT-23_Handsoldering | C181151
SI2302DS NMOS/GSD N-MOSFET transistor, gate/source/drain | Q4 | SOT-23_Handsoldering
QBC817 NPN/BEC NPN transistor, base/emitter/collector | Q5 | SOT-23_Handsoldering
10k/R0402 | R1,R2,R8,R9,R13,R16,R17,R18,R21 | R_0402_1005Metric_Pad0.72x0.64mm_HandSolder | C25744
220k/R0402 | R4 | R_0402_1005Metric_Pad0.72x0.64mm_HandSolder | C25767
470k/R0402 | R5,R10,R11 | R_0402_1005Metric_Pad0.72x0.64mm_HandSolder | C25790
2.2k/R0402 | R6,R7,R12,R14 | R_0402_1005Metric_Pad0.72x0.64mm_HandSolder | C25879
220/R0402 | R15 | R_0402_1005Metric_Pad0.72x0.64mm_HandSolder | C25091
0 /R0402 | R19 | R_0603_1608Metric_Pad0.98x0.95mm_HandSolder | C17168
4,7k/R0402 | R20 | R_0402_1005Metric_Pad0.72x0.64mm_HandSolder | C25900
IT-1185AU2-160G-G-TR | RST1 | SW_SPST_B3U-3000P
SW_DIP_x04 4x DIP Switch, Single Pole Single Throw (SPST) switch, small symbol | SW1 | DSHP04TSS | C319050
ESP32-WROVER | U1 | XCVR_ESP32-WROVER-I | C503591
CH340T(SSOP20W) | U3 | SSOP20-0.65-7.6X5.2MM | C8689
AMS1117-3.3 1A Low Dropout regulator, positive, 3.3V fixed output, SOT-223 | U4 | SOT-223-3_TabPin2 | C6186

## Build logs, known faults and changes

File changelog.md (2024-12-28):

# Changelog

## DEV-branch

* 27.12.2024: Fix audio dropouts in BT-Source mode
* 27.12.2024: ArduinoJson 7 (#357)
* 18.12.2024: Use saved SSID as LAST_SSID, when no successfull connection was possible #355, thanks to @nona00 !
* 18.12.2024: Check if #POWER defined, thanks to @QDaniel !
* 18.12.2024: Prepare for Arduino 3.1.0
* 16.12.2024: Add verbose log to indicate, that the restart is on purpose (#356), thanks to @thebino !
* 16.12.2024: LPCD: Only wake up if card is present in NVS (#352), thanks to @fox34 ! 
* 25.11.2024: Moving some settings to the Web UI (#350), thanks to @trainbird !
* 17.11.2024: Simplify 'SdCard_ParseM3UPlaylist' and fix parsing, thanks to @h4kun4m4t4t4 !
* 29.10.2024: Update Audio lib
* 29.10.2024: Enable CONFIG_ESP32_REV_MIN_3 to save some IRAM
* 22.10.2024: Cleaning up `management.html` (#348), thanks to @trainbird !
* 22.10.2024: Update Arduino-IRremote to support the ESP 3.0 core
* 29.09.2024: Removal of support for non-PSRAM HALs (Lolin32, LolinD32, DevkitC) and ESP32-A1S
* 29.09.2024: Prepare for Arduino 3.0.5
* 27.09.2024: PlatformIO package 6.9.0

## Version 2.3 (23.09.2024)

* 19.09.2024: Document the virtual cards in the UI #333, thanks to @caco3 !
* 18.09.2024: Re-designed tools page (#337), thanks to @caco3 !
* 16.09.2024: Fix sleep after playlist not toggling nightmode #336, thanks to @dneukirchen !
* 12.09.2024: PlatformIO package 6.8.1 (Arduino 2.0.17, ESP-IDF 4.4.7)
* 12.09.2024: Change default settings to match "ESPuino-mini 4Layer" board
* 11.09.2024: Fix string's expected length for rfid-cmnd via mqtt
* 11.09.2024: Ignore mqtt messages with length zero
* 10.09.2024: Porting to new web server library completed
* 09.06.2024: Consume about 50% less CPU time in Audio library
* 09.06.2024: Replace 3rd party library toastr (#331), thanks to @trainbird !
* 09.06.2024: Modernized webserver & optimized JSON delivery (#332)
* 20.05.2024: PlatformIO package 6.7.0 (Arduino 2.0.16, ESP-IDF 4.4.7)
* 20.05.2024: Disable bluetooth support for A1S (IRAM too small)
* 09.05.2024: Upgrade to Bootstrap v5.0 + Web-UI Enhancements (#328), thanks to @caco3 !
* 23.04.2024: Enhance UI minification (#323), thanks to @caco3 !
* 22.04.2024: Added virtual RFID-Cards (#319), thanks to @caco3 !
* 18.04.2024: Correct calculation of newFilePos for SEEK_POS_PERCENT, thanks to @sfields!
* 18.04.2024: Correct calculation of gPlayProperties.currentRelPos, thanks to @sfields!
* 18.04.2024: Get title from-VORBISCOMMENT and ID3, thanks to @sfields!
* 18.04.2024: Correct log for SSID name, thanks to @sfields!
* 18.04.2024: Add button to expand/shrink file list (#317), thanks to @caco3 !
* 18.04.2024: Fix remote UI debugging (#316), thanks to @caco3 !
* 14.04.2024: Embed swagger UI #314, thanks to @caco3 !
* 07.04.2024: Equalizer settings to WebUI #313, thanks to @trainbird !
* 28.03.2024: Audio lib, fix a memory leak with flac files
* 28.03.2024: Fix some warnings with upcoming Arduino 3 (ESP-IDF v5.1)
* 16.03.2024: Reduce memory usage by measurement of JSON payload length
* 15.03.2024: MQTT receive: Bug fix and avoid payload copy (#309), thanks to @eikel
* 15.03.2024: Add coverimage support for ogg, vorbis, opus (and some flac), thanks to @sfields !
* 19.02.2024: Add coverimage support for M4A files in Web-UI
* 18.02.2024: Add coverimage support for flac files in Web-UI, thanks to @sfields !
* 15.02.2024: Rework playlist generation (#275), thanks to @laszloh !
* 15.02.2024: Update sorting strings (#306), thanks to @freddy36 !
* 15.02.2024: Set title and navbar heading to hostname (#305), thanks to @freddy36 !
* 15.02.2024: Include mac address in info (#304), thanks to @freddy36 !
* 12.02.2024: Use natural sort (#296), thanks to @freddy36 !
* 09.02.2024: Remove explorerCreateParentDirectories (#301), thanks to @freddy36 !
* 08.02.2024: Remove convertFilenameToAscii (#298), Playlist fixes (#299), thanks to @freddy36 !
* 08.02.2024: Apple touch icon
* 07.02.2024: Fix dangling pointer in explorerHandleFileStorageTask (#297), thanks to @freddy36 !
* 07.02.2024: Reduce WiFi memory consumption (#295), thanks to @laszloh !
* 05.02.2024: Increase JSON buffer for /debug endpoint
* 02.02.2024: Improve progress calculation/indication, thanks to @freddy36 !
* 01.02.2024: Use NVS interator when reading RFID keys, save 4KB RAM , thanks to @laszloh !
* 01.02.2024: Use dynamically allocated buffer for file upload, save 32KB RAM , thanks to @laszloh !
* 30.01.2024: Add French Language (#292), thanks to @damda58 !
* 30.01.2024: Fix some audio dropouts with high-quality OPUS files
* 30.01.2024: Keep original mtime for gzip compressed files, avoiding uneccesary Web.o rebuilds (#293), thanks to @freddy36 !
* 23.01.2024: Updated documentation on LPCD setting, thanks to @derpicknicker1 !
* 21.01.2024: Build (tag 2.2) is broken when NEOPIXEL_ENABLE is not set #289, thanks to @RolinBert !
* 21.01.2024: PN5180: Save about 500 Bytes of RAM

## Version 2.2 (17.01.2024)

* 14.01.2024: Modify CMD_DIMM_LEDS_NIGHTMODE to toggle night light mode (#287), thanks to @laszloh !
* 11.01.2024: More free heap on boards with PSRAM (CONFIG_SPIRAM_MALLOC_ALWAYSINTERNAL)
* 10.01.2024: LPCD for ISO-15693 cards
* 05.01.2024: REST-API specification, thanks to @pauel !
* 02.01.2024: Partly revert: Fix webstream playlist abort when track fails (#285), thanks to @sfields !
* 02.01.2024: Show critical voltage slider only if SHUTDOWN_ON_BAT_CRITICAL defined
* 29.12.2023: Show station logo in Web-UI (if available)
* 29.12.2023: /rfid endpoint: List all assigned nvs entries (#280)
* 29.12.2023: Enhanced capabilities for task runtime debugging
* 28.12.2023: Bugfix 1: DONT_ACCEPT_SAME_RFID_TWICE_ENABLE and web frontend, thanks to @sfields !
* 28.12.2023: Add configuration for critical (shutoff) voltage in Web-UI, thanks to @SZenglein !
* 28.12.2023: New official PlatformIO package 6.5.0 (Arduino 2.0.14, ESP-IDF 4.4.6)
* 28.12.2023: Improve port expander handling (#283), thanks to @r-schmidt !
* 23.12.2023: Update audio library, avoid waiting in i2s_channel_write() to have more time in other tasks #636
* 22.12.2023: Web-UI: Preselection of root folder after load to avoid nasty warning when uploading files
* 17.12.2023: Update audio library, fixes click-noise seeking in file
* 13.12.2023: Immediately go to sleep if battery is critical (#274), thanks to @SZenglein !
* 12.12.2023: Long press behaviour, execute cmd directly after longpress-time (#279), thanks to @Joe91 !
* 12.12.2023: Fix false-positive error (Audio playback timeout)
* 10.12.2023: Distribute vTaskDelay() in main loop to avoid rare audio dropouts
* 10.12.2023: Fix wrong states on PE output pins (and SD-card failure on restart) #278, thanks to @36b6fp6s !
* 09.12.2023: Fix webstream playlist abort when track fails (#276), thanks to @laszloh !
* 07.12.2023: Show RC522 firmware version at startup, same as PN5180
* 04.12.2023: fix stuttering sound with some WAV & MP3 files, thanks to @wolle !
* 04.12.2023: change trackprogress communication from websocket to http to improve stability
* 04.12.2023: Remove some convertAsciiToUtf8() #272
* 30.11.2023: Fix a nullptr access after trying to replay an invalid filename (#271), thanks to Olaf!
* 29.11.2023: Updated audio library to play more MP3s, faster track change & delivery of the cover image
* 25.11.2023: Save some cpu time in audio task by only updating the playtime statistics every 250ms
* 22.11.2023: Web-UI: Search for files feature #268
* 21.11.2023: New command CMD_TOGGLE_MODE to switch Normal => BT-Sink => BT-Source
* 21.11.2023: Bugfix: Some commands e.g. Play/Pause did not work in BT-Source mode
* 21.11.2023: Faster pairing animation in BT-Source mode to better distinguish between the two BT modes
* 19.11.2023: Give audiotask a higher task priority, fixes crackling sound
* 19.11.2023: bugfix_same_rfid_twice init #262, see Github comments
* 17.11.2023: Show track progress, current playtime & duration in web-ui (#267)
* 16.11.2023: Fix delay with getLocalTime()
* 14.11.2023: Multi Wlan improvements (#266), thanks to @laszloh !
* 13.11.2023: Update third party libraries
* 08.11.2023: Fix HTML syntax errors, found with static code analysis tool "HtmlHint"
* 08.11.2023: Better logging for boards without PSRAM, fewer logs when compiling with NO_SDCARD
* 07.11.2023: Set timezone after startup, thanks to @Joe91 !

## Version 2.1 (07.11.2023)

* 04.11.2023: LPCD: wakeup check for ISO-14443 cards also with IRQ connected to port-expander
* 04.11.2023: Bugfix for showing wrong loglevel
* 03.11.2023: Web-ui: Fix overlapping info/log after pressing refresh button
* 01.11.2023: Fix folder upload with special chars & playtime formatting
* 31.10.2023: Code Formatting via clang-format #264, thanks to @laszloh & @fschrempf !!
* 27.10.2023: PlatformIO package 6.4.0, Arduino version stays at 2.0.11
* 26.10.2023: LPCD, RFID_IRQ on port-expander: fix compiler warning
* 26.10.2023: portTICK_RATE_MS is deprecated, use portTICK_PERIOD_MS instead (<https://github.com/espressif/esp-idf/issues/51>)
* 26.10.2023: Cppcheck: Fix some warnings/hints
* 22.10.2023: Bugfix PortExpander: beginTransmission()/endTransmission() must be balanced
* 21.10.2023: Enhanced logging: Show Loglevel
* 14.10.2023: New define NO_SDCARD, enable to start without any SD card, e.g. for a webplayer only.
* 05.10.2023: Enable "Arduino as component" by default
* 02.10.2023: Optimize Arduino as component (Disable BLE, BT-HFP & SPI ethernet)
* 25.09.2023: Handle unicode characters in NVS backup, write UTF-8 BOM in backup.txt
* 23.09.2023: Fix some log messages, update FTP & A2DP libraries
* 22.09.2023: Bugfix_same_rfid_twice init (#262) - Thanks to @Joe91 !!
* 06.09.2023: Arduino as component #261 - Thanks to @Joe91 !!
* 01.09.2023: Regression: start an initial WiFi scan on startup, fix redirect to captive portal
* 31.08.2023: Show nvs rfid assignments in web-ui & allow to delete single tags
* 31.08.2023: invoke "/rfid" endpoint (#260)
* 22.08.2023: Unify endpoints for accesspoint.html/management.html (#258)
* 15.08.2023: Web-ui: Change /restart endpoint to POST, refresh button for info & log modal
* 12.08.2023: Web-ui improvements
* 08.08.2023: check & avoid excessive "PING" calls from web-ui
* 08.08.2023: Configurable volumecurve #256, thanks to @Niko & @Wolle
* 08.08.2023: Refactor "/info" endpoint to make frontend/backend more independant #257
* 07.08.2023: LOG message for starting mDNS service
* 04.08.2023: Support for .oga audio files (Ogg Vorbis Audio container)
* 04.08.2023: Web-UI: Replace the template processor (#253)
* 02.08.2023: Bugfix M3U-playlist + PREVIOUSTRACK, thanks to @Niko!
* 31.07.2023: Restart system: avoid peripheral power down while restarting
* 31.07.2023: increase stacksize for audio-task (audio-streams with SSL)
* 22.07.2023: New command CMD_TELL_CURRENT_TIME for announcing the current time
* 21.07.2023: Show overall playtime total in web-ui
* 21.07.2023: Refactor shutdown procedure, add new command CMD_RESTARTSYSTEM
* 20.07.2023: Allow to configure the timezone in settings.h
* 19.07.2023: Show received timestamp of NTP request in log
* 11.07.2023: Fix regression, SD-card was not working in SPI mode
* 09.07.2023: New ftp server by peterus #254. Thanks to @Joe91 for contribution !!
* 08.07.2023: Allow to compile without SD-card (webplayer only)
* 04.07.2023: fix volume jumping at startup when initVolume <> factory default (3u)
* 29.06.2023: Update PN5180 library to fix compilation with DCORE_DEBUG_LEVEL=5
* 25.06.2023: Some spelling corrections, thanks to @SciLor !
* 23.06.2023: CMD_TELL_IP_ADDRESS: IP as text (replace thousand separator with word "point")
* 23.06.2023: web-upload improvement (#249). Thanks to @Joe91 !!
* 23.06.2023: Refactor web: Move dependant html-code from web.cpp to management.html (#250)
* 20.06.2023: PlatformIO package 6.3.2
* 20.06.2023: Move ScanWiFiOnStart to global WiFi configuration (#248)
* 18.06.2023: Stricter hostname validation (#246). Thanks to @SZenglein !!
* 18.06.2023: Some Web-UI improvements (#247)
* 17.06.2023: CMD_TOGGLE_WIFI_STATUS: Escape from BT-mode, WiFi cannot coexist with BT and can cause a crash
* 13.06.2023: Bluetooth configuration tab in web-interface (#244)
* 13.06.2023: Introduce new playmode "RANDOM_SUBDIRECTORY_OF_DIRECTORY_ALL_TRACKS_OF_DIR_RANDOM"
* 07.06.2023: Use bssid to connect to best WIFI and added option to always perform a WIFI-scan #241
* 06.06.2023: List available WiFi's in accesspoint view
* 06.06.2023: Remove support for Arduino 1.0.6 & playlist cache
* 05.06.2023: FastLED 3.6.0, PlatformIO package 6.3.1
* 01.06.2023: Improve neopixel display in Bluetooth speaker mode (BT-Sink) (#239)
* 01.06.2023: Reduce floating the log with redundant RSSI-messages: Log RSSI value only if it has changed by > 3 dBm
* 31.05.2023: Wifi: Log BSSID in scan and connection success, Wifi fixes (#240)
* 26.05.2023: Fix compiler warnings if MQTT_ENABLE is not defined
* 26.05.2023: Error in log: `[E][Preferences.cpp:96]` remove(): nvs_erase_key fail
* 23.05.2023: Migration from single-wifi setup: Initialize "use_static_ip"
* 22.05.2023: DEV branch has stricter compiler rules, fix some of (mostly harmless) warnings
* 22.05.2023: BTSource: fix Stack canary watchpoint triggered (BtAppT)
* 19.05.2023: Show Arduino version at startup & in web-info
* 19.05.2023: Add support for saving multiple wifi networks (#221)
* 09.05.2023: Bluetooth.cpp: Fix logging crash in sink mode (#238)
* 06.05.2023: README.md: Improve formatting, style, language and content
* 03.05.2023: Add support for control LEDs to be connected at the end of the NeoPixel Ring (#198)
* 27.04.2023: Remove usage of pgmspace.h header
* 27.04.2023: Move message formatting into LogMessages
* 26.04.2023: Configure button with active HIGH
* 20.04.2023: Speedup playlist generation & file listing by factor > 20
* 14.04.2023: Removing HAL for ESPmuse (stale development)
* 12.04.2023: Restrict value ranges to guard array access
* 11.04.2023: Merge pull request #226 from fschrempf/bugfix_rfid_assign
* 08.04.2023: Enforcing uniform codestyle
* 08.04.2023: Allow to escape from bluetooth mode with an unknown card, switch back to normal mode
* 03.04.2023: Merge pull request #223 from laszloh/bugfix/snprintf_warning, fix for snprintf trunctation warnings
* 03.04.2023: Add missing translations
* 31.03.2023: build.yml: Trigger workflow for all branches
* 27.03.2023: Merge pull request #219 from laszloh/feature/modern_cpp
* 25.03.2023: Transition to c++17
* 24.03.2023: Lost feature „PLAY_LAST_RFID_AFTER_REBOOT“
* 23.03.2023: Change volume animation to triggered mode
* 22.03.2023: Merge pull request #215 from fschrempf/execute-commands
* 22.03.2023: Change rotary encoder to delta mode
* 22.03.2023: Fix errorous indicator in case no audio is playing
* 22.03.2023: Fix for stuck LED-Shutdown animation
* 21.03.2023: Pause some tasks for speedup & smoother HTTP upload
* 21.03.2023: Feature: command-execution on control-site of webserver
* 21.03.2023: Merge pull request #210 from fschrempf/led_rework_cleaned_frieder
* 21.03.2023: Set default environment to arduino2 on dev-branch
* 18.03.2023: Bugfix: Corrupted files after HTTP-upload
* 18.03.2023: Major rework of LED animation task
* 13.03.2023: Fix for playing files via Web-UI for Arduino >=2.0.5
* 13.03.2023: Fix captive portal, Add fallback text AP setup
* 10.03.2023: Merge pull request #204 from laszloh/bugfix/heap_handling
* 10.03.2023: Always free playlist memory when SdCard_ReturnPlaylist is called
* 10.03.2023: Fix heap corruption due to insufficent memory allocation
* 10.03.2023: Harmonize return value of SdCard_ReturnPlaylist
* 10.03.2023: Correct the name of the "sort" function to randomize
* 10.03.2023: Create DEV(eloper) branch

## Version 1

* 22.04.2021: Introduced refactoring-branch
* xx.05.2021: Fixing/stabilizing code
* 08.06.2021: Added global support for PA/HP-enable
* 15.06.2021: Added interrupt-handling to PCA9555
* 22.06.2021: Changed ESP32's partition-layout in order to provider bigger NVS-storage
* 30.06.2021: Added directive `CACHED_PLAYLIST_ENABLE` for faster playlist-generation
* 08.07.2021: Added support to monitor WiFi's RSSI
* 09.07.2021: Making branch `refactoring` the the master
* 09.07.2021: Making master the new branch `old` (not maintained any longer!)
* 13.07.2021: Adding OTA-support via webGUI
* 23.07.2021: Adding new playmode: from local .m3u-file (files or webstreams)
* 30.09.2021: Added feature `PAUSE_WHEN_RFID_REMOVED` for RC522 after having it already for PN5180 (thanks @elmar-ops for contribution)
* 27.10.2021: Added feature `SAVE_PLAYPOS_BEFORE_SHUTDOWN`. When enabled last playposition for audiobook is saved when shutdown is initiated. Without having this feature enabled, it's necessary to press pause first, in order to do this manually.
* 28.10.2021: Added feature `SAVE_PLAYPOS_WHEN_RFID_CHANGE`. When enabled last playposition for audiobook is saved when new RFID-tag is applied. Without having this feature enabled, it's necessary to press pause first, in order to do this manually.
* 13.11.2021: Command `CMD_TELL_IP_ADDRESS` can now be assigned to buttons in order to get information about the currently used IP-address via speech.
* 29.01.2022: Directive `INVERT_POWER` can now be used it invert power-GPIO. And port-expander can now be used for power.
* 28.02.2022: Directive `MEASURE_BATTERY_MAX17055` added. Provides support for [MAX17055](https://www.maximintegrated.com/en/products/power/battery-management/MAX17055.html).
* 31.08.2022: Directive `DONT_ACCEPT_SAME_RFID_TWICE` added. Blocks unwanted reapplies of the same rfid-tag (in case it's not a modification-card or rfid-tag is unknown in NVS).
* 02.10.2022: ESPuino is now able to stream audio to external BT-devices. This is currently in testing. Big thanks to @tueddy for providing this feature!
* 18.10.2022: New playmode: pick random subdirectory of a given directory and play it's content alphabetic ordered
* 08.01.2023: New feature: `PAUSE_ON_MIN_VOLUME`. Playback is paused automatically if volume reaches minVolume (usually 0).

## Old (monolithic main.cpp)

* 11.07.2020: Added support for reversed Neopixel addressing.
* 09.10.2020: mqttUser / mqttPassword can now be configured via webgui.
* 16.10.2020: Added English as supported lanuage.
* 01.11.2020: Added directive `SD_NOT_MANDATORY_ENABLE`: for debugging puposes SD can be bypassed at boot.
* 17.11.2020: Introduced a distinct volume for headphone for optional headphone-PCB.
* 20.11.2020: Added directive `MEASURE_BATTERY_VOLTAGE`: monitoring battery's voltage is now supported.
* 25.11.2020: WiFi can now be enabled/disabled instantly by pressing two buttons.
* 28.11.2020: Battery's voltage can now be visualized by Neopixel by short-press of rotary encoder's button.
* 28.11.2020: Added directive `PLAY_LAST_RFID_AFTER_REBOOT`: ESPuino will recall the last RFID played after reboot.
* 05.12.2020: Added filebrowser to webgui (thanks @mariolukas for contribution!)
* 05.12.2020: Moved all user-relevant settings to src/settings.h
* 06.12.2020: Added PCB for Wemos Lolin32
* 08.12.2020: Reworked MQTT-timeout-Management
* 09.12.2020: mDNS-feature added. If ESPuino's name is "ESPuino", you can use `ESPuino.local` instead it's of IP-address.
* 11.12.2020: Revised GUI-design (thanks @mariolukas for contribution!) + (untested) PCB added for Wemos Lolin D32 + gerberfiles for headphone-PCB
* 18.12.2020: Added SD-MMC 1 Bit-mode (`SD_MMC_1BIT_MODE`). This mode needs one GPIO less and provides almost doubled speed (compared to SPI) for FTP-transfers (thanks @tueddy for contribution!)
* 18.12.2020: Added support for RFID-reader PN5180 (`RFID_READER_TYPE_PN5180`). PN5180 has better RFID-range/sensitivity and can read ISO-15693 / iCode SLIX2-tags aka 'Tonies' (thanks @tueddy for contribution!)
* 20.12.2020: Due to memory-issues with webstreams, FTP needs to be activated by pressing pause+next-button now
* 23.12.2020: User-config is now split into general part (settings.h) and develboard-specific part (e.g. settings-lolin32.h)
* 13.01.2021: Added fileexlorer to webgui (thanks @grch87 for contribution!). Now files and directories can be renamed, uploaded and deleted via webgui.
* 17.01.2021: Added directive `STATIC_IP_ENABLE`: (optional) static IPv4-configuration
* 18.01.2021: Added directive `PN5180_ENABLE_LPCD`: awake from deepsleep with PN5180 is now possible (but needs another GPIO)
* 25.01.2021: Added directive `USE_LAST_VOLUME_AFTER_REBOOT`: Remembers volume used at last shutdown after reboot. This overwrites initial volume from GUI.
* 28.01.2021: Removed cached RFID-filebrowser and replaced by realtime-browser
* 01.02.2021: Introducing PCB: Lolin32 with SD_MMC + PN5180
* 06.02.2021: German umlauts now supported. When uploading via FTP make sure to change charset to CP437.
* 09.02.2021: Added support for bluetooth-sink (a2dp). Thanks @grch87 & @elmar-ops for providing this feature!
* 25.02.2021: Added support for dynamic button-layout. Rotary-encoder is now optional and up to five buttons can be used.
* 25.02.2021: Actions can be freely assigned to buttons (multi-button, single-button (short), single-button (long))
* 25.02.2021: Added support for webcontrol: basic control (volume, play/pause, next, previous, first, last track) can now be controlled via webgui.
* 25.02.2021: Added support for .m4a and .wav-files.
* 26.02.2021: Shutdown via webgui is now available.
* 05.03.2021: Added support for remote control via infrared. Make sure to enable `IR_CONTROL_ENABLE` to use this feature and don't forget to assign corresponding rc-commands of *your* remote control to actions.
* 19.03.2021: Added support for port-expander PCA9555. Can be used for everything, that is "button-like": buttons, headphone-detect, PN5180.IRQ.
* 28.03.2021: Added support for fileseek. With commands `CMD_SEEK_FORWARDS` and `CMD_SEEK_BACKWARDS` it's possible to jump a number of seconds defined in `jumpOffset`.
* 30.03.2021: Added support for stereo/mono via `PLAY_MONO_SPEAKER`. If active, mono is used while headphones remain stereo (if `HEADPHONE_ADJUST_ENABLE` is active).
* no more updates will follow!

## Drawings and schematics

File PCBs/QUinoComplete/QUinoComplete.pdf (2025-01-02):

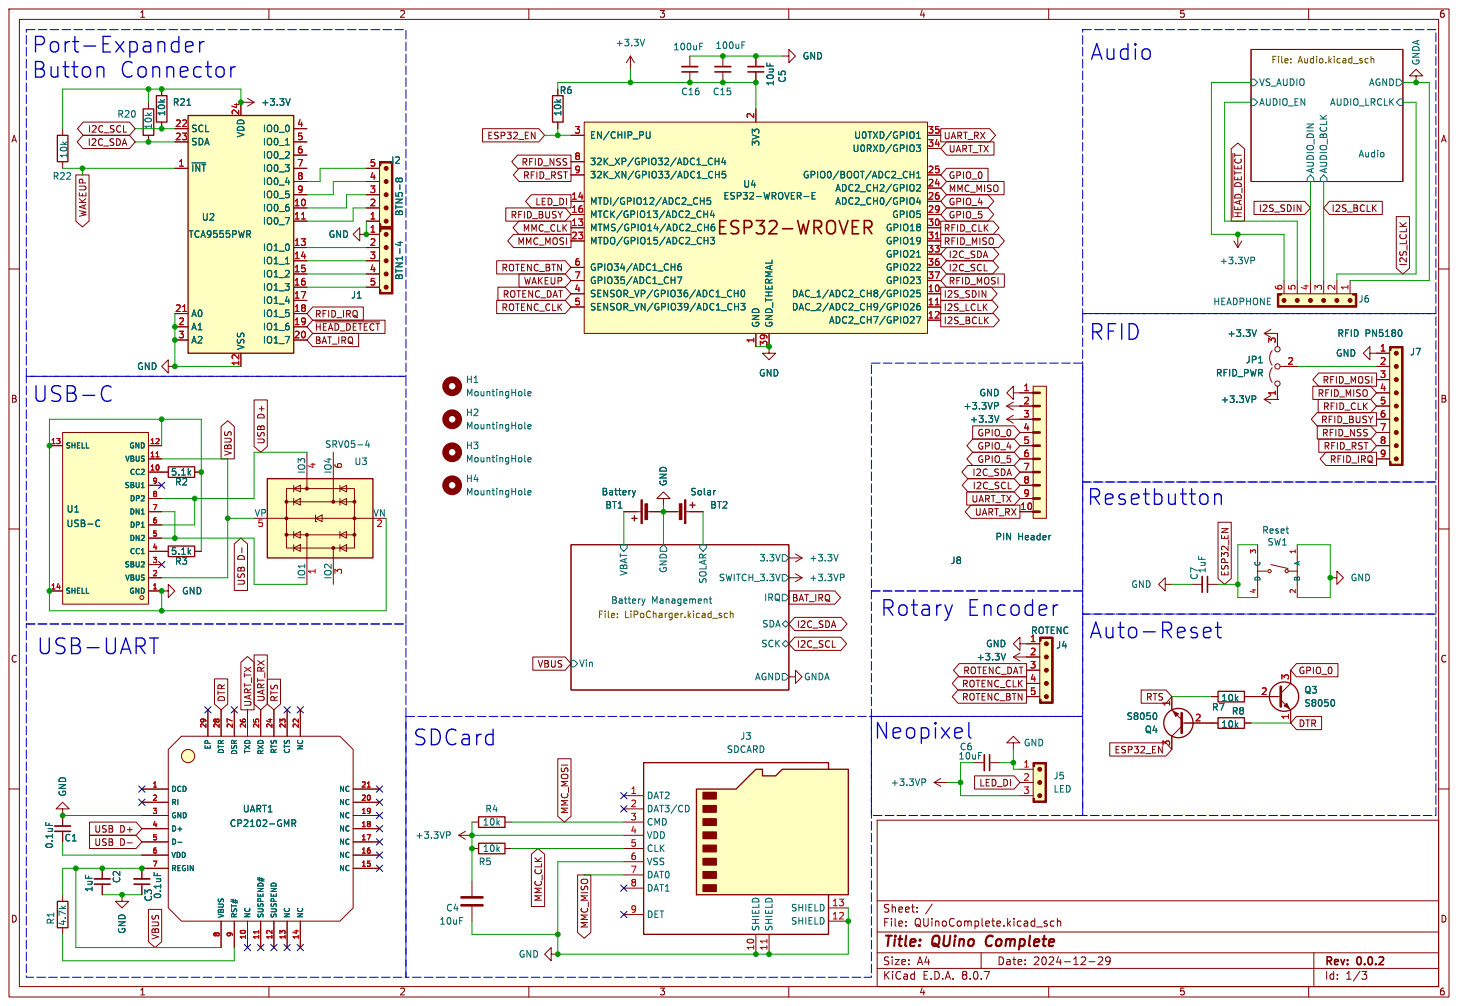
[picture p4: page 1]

Battery Management File: LiPoCharger.kicad_sch

File: QUinoComplete.kicad_sch Sheet: /
Id: 1/3 Title: QUino Complete

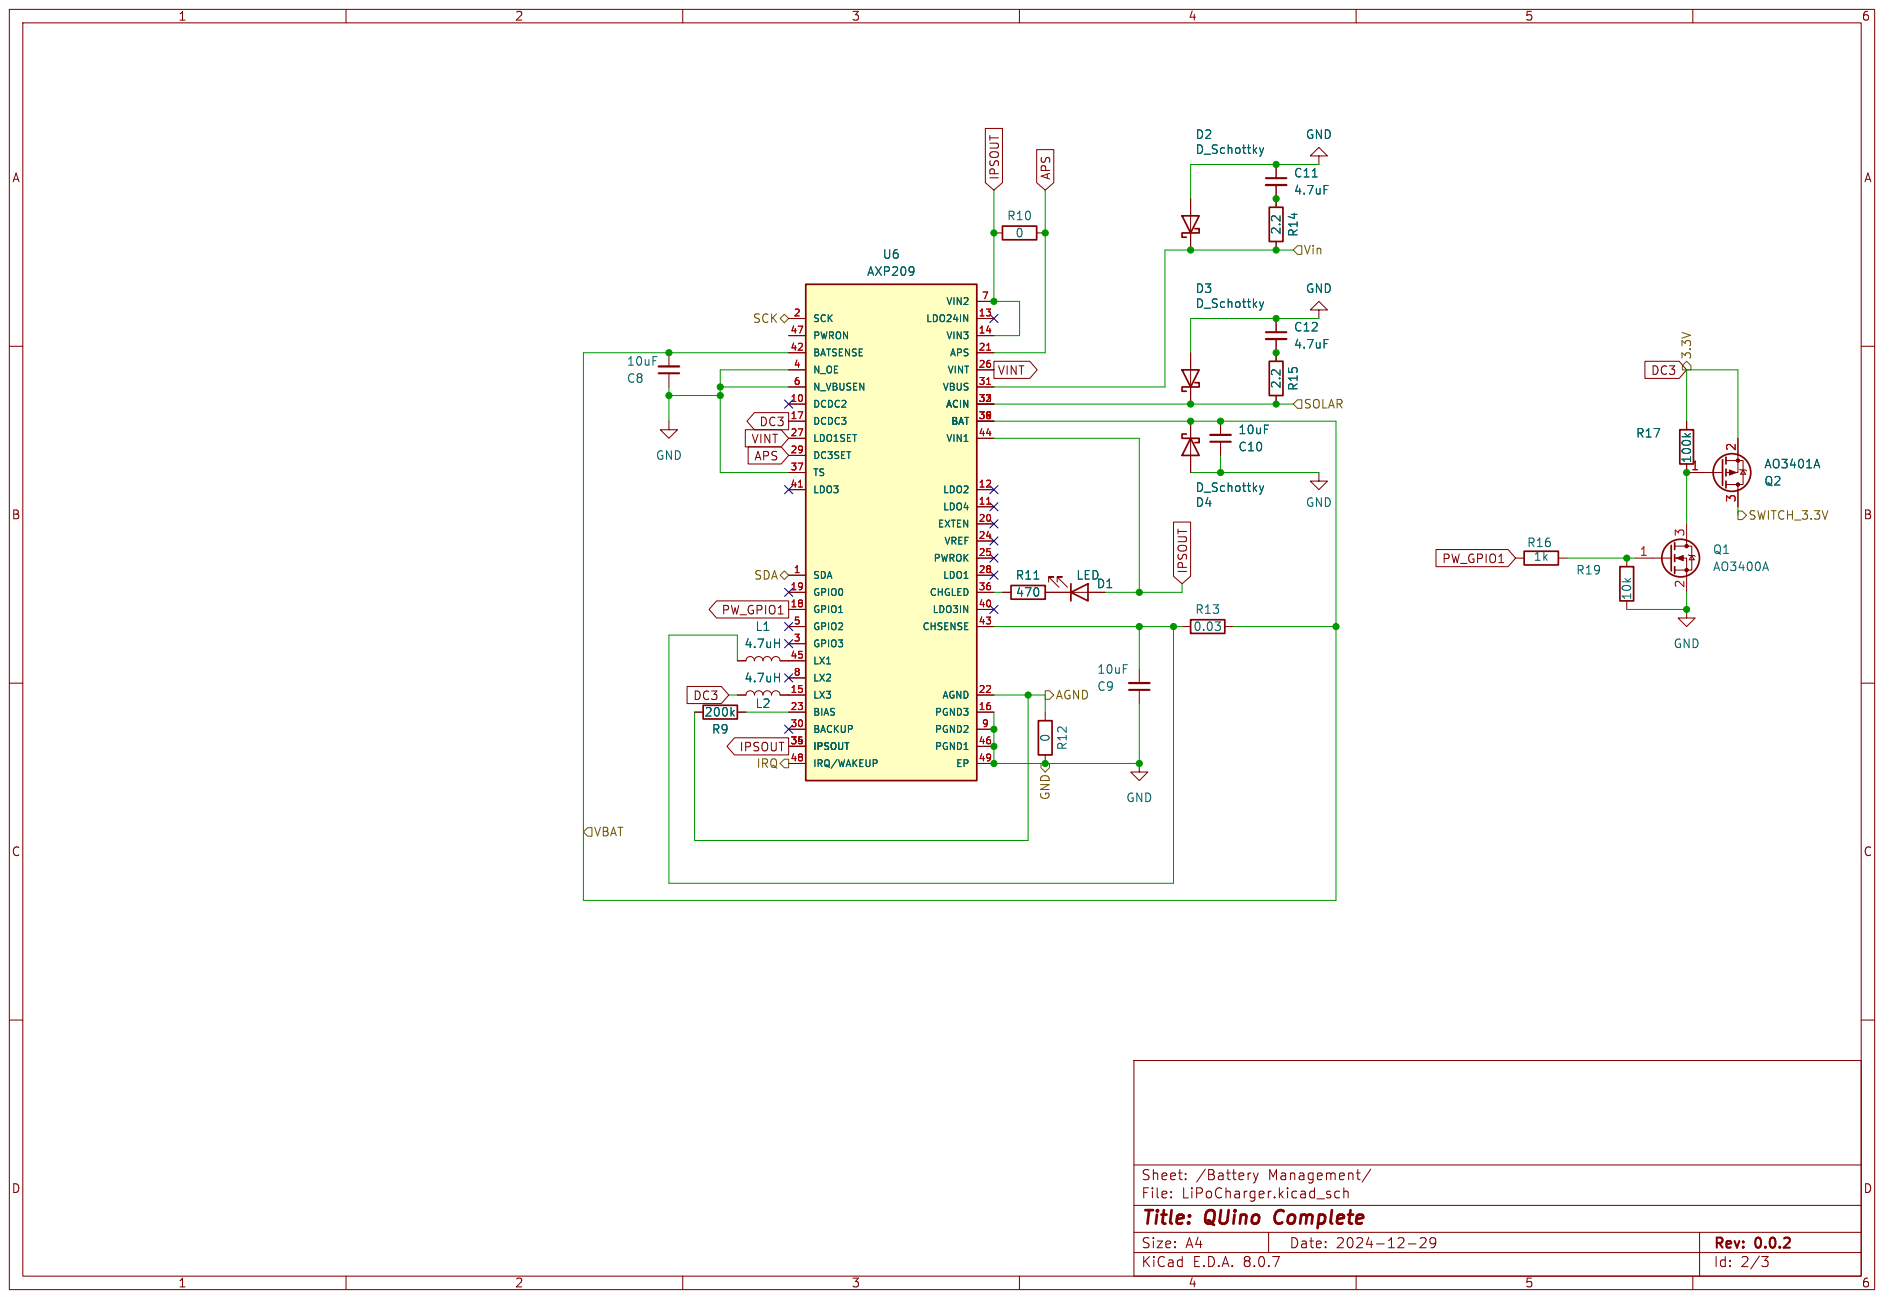
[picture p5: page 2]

Id: 2/3 Title: QUino Complete

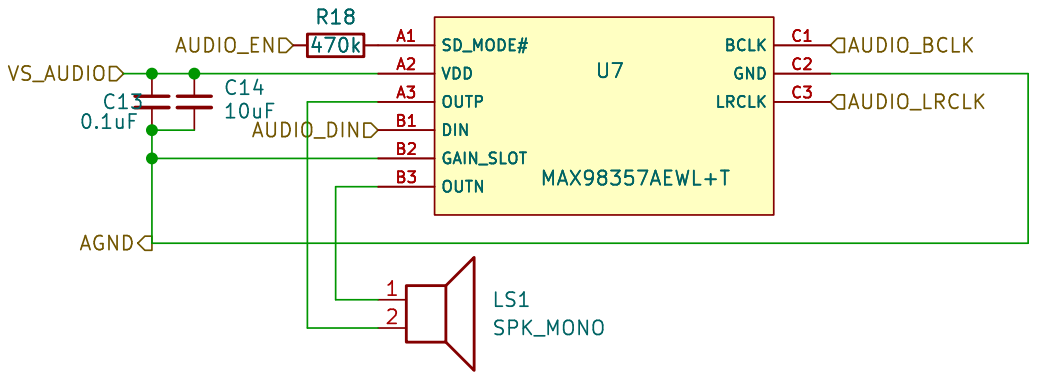
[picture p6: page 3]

File: Audio.kicad_sch Sheet: /Audio/
Id: 3/3 Title: QUino Complete

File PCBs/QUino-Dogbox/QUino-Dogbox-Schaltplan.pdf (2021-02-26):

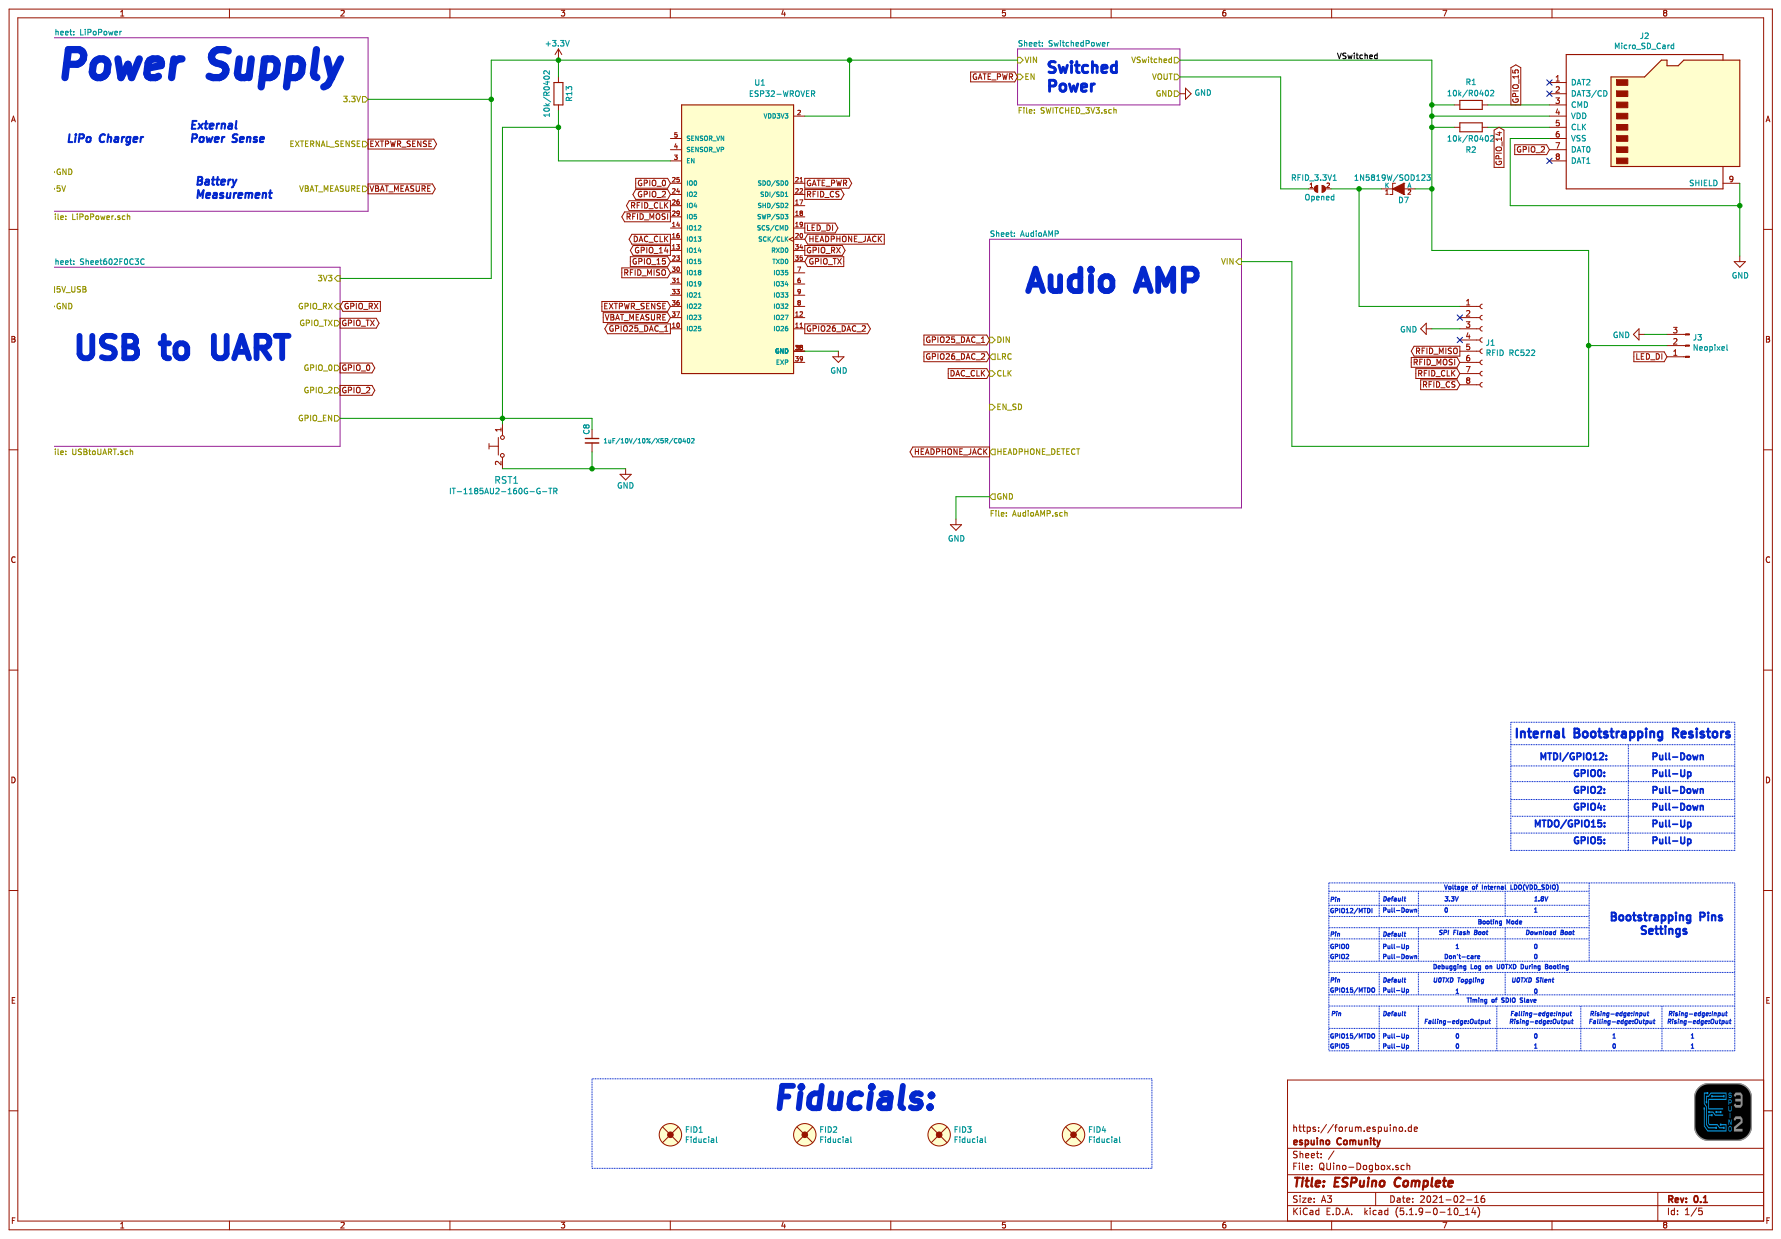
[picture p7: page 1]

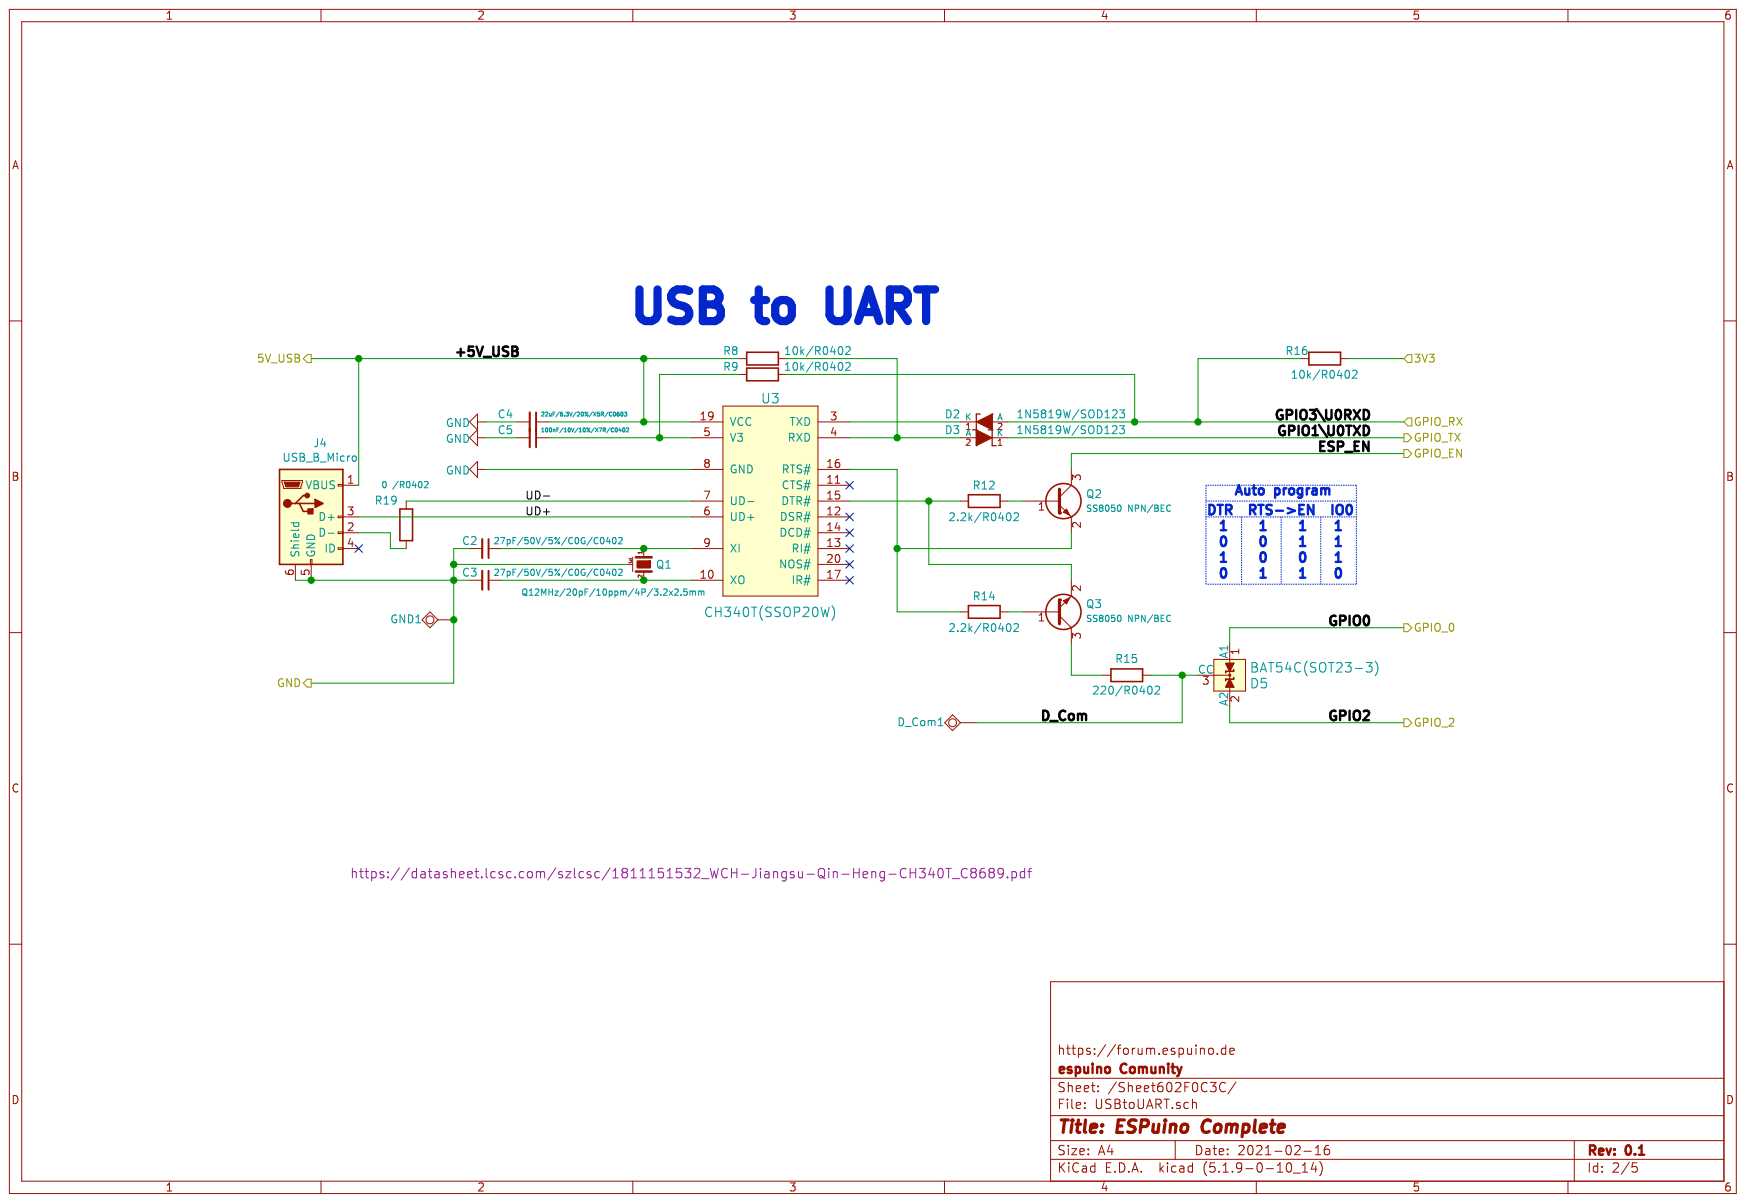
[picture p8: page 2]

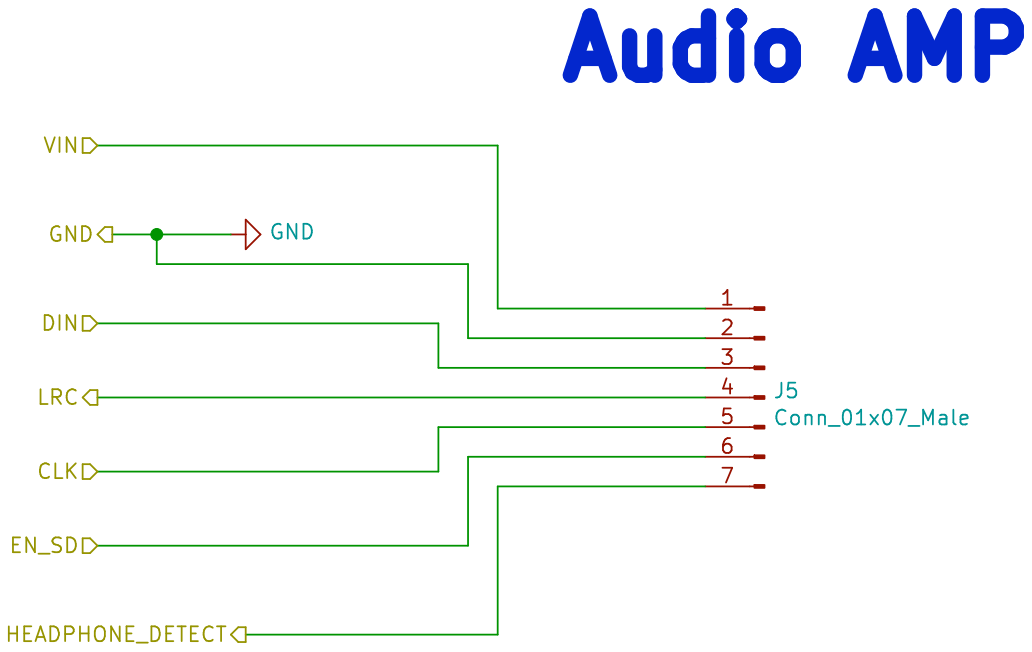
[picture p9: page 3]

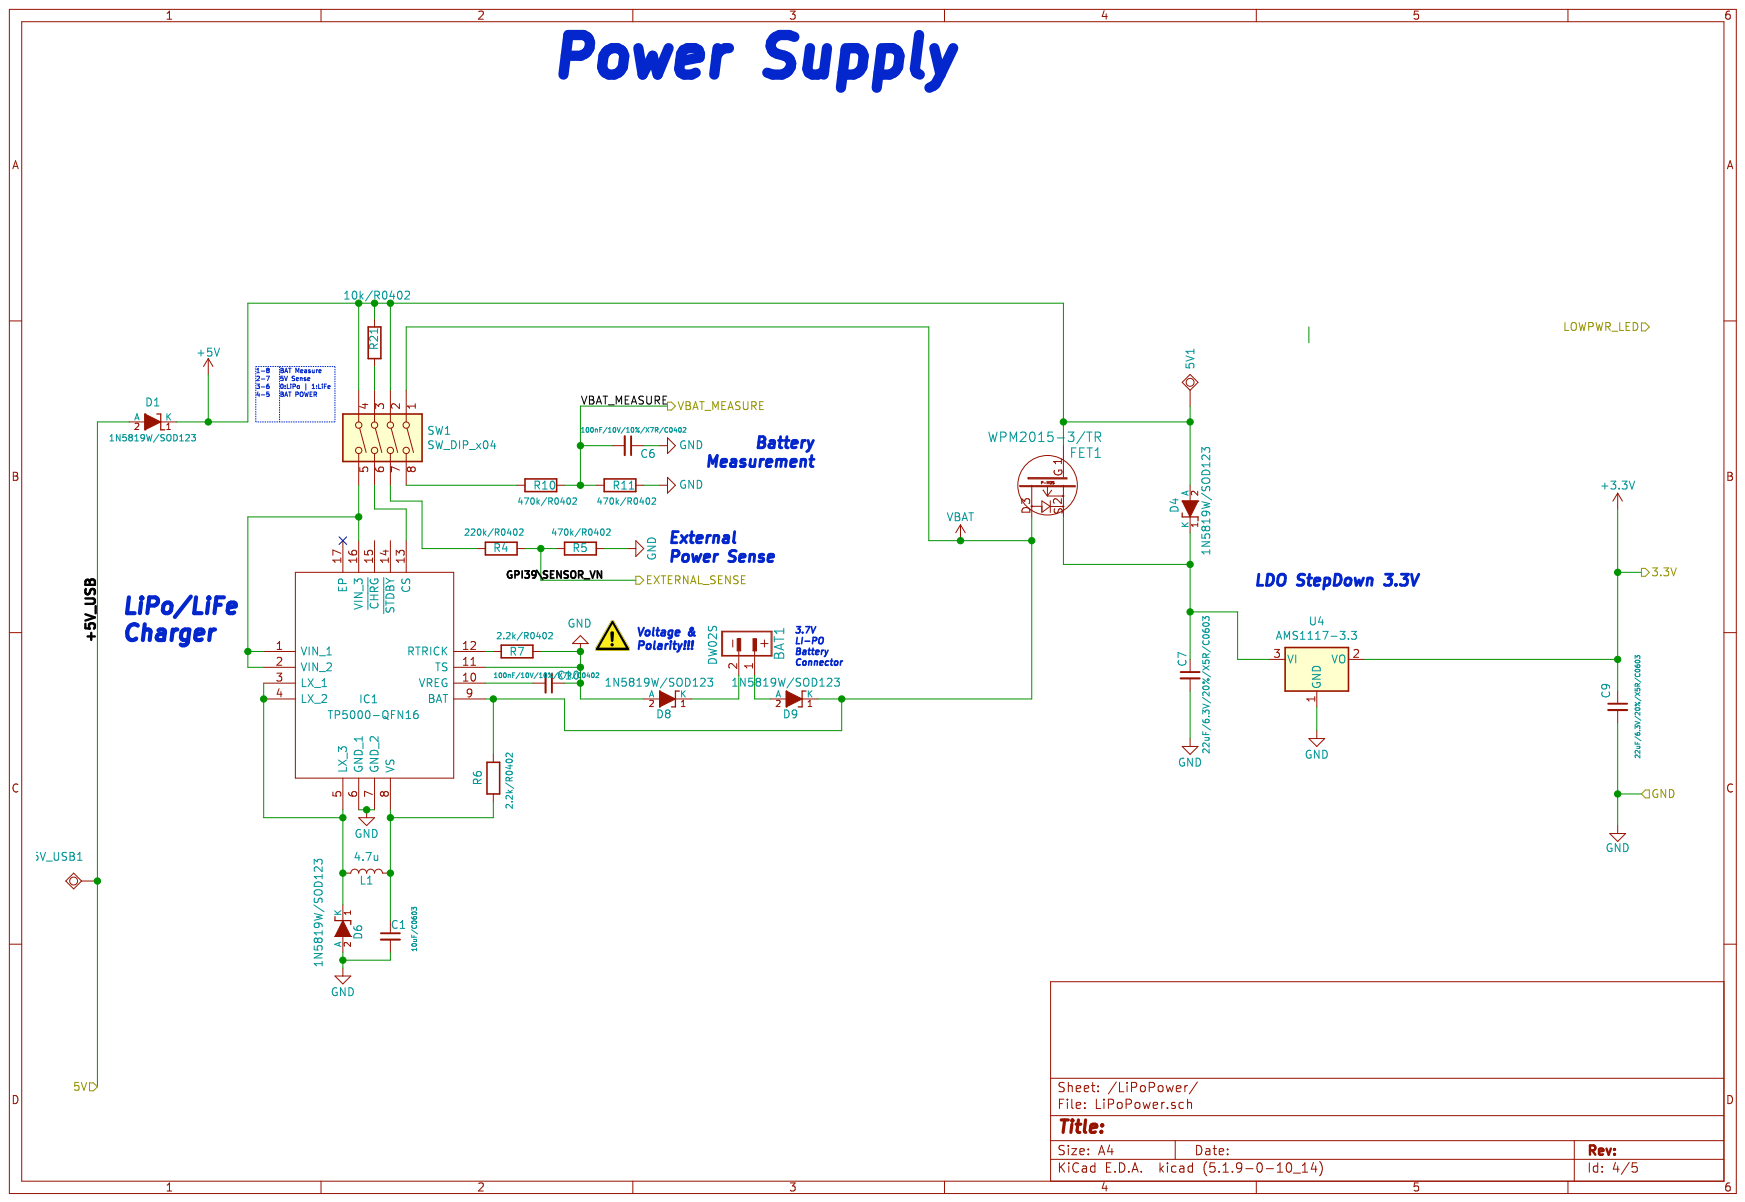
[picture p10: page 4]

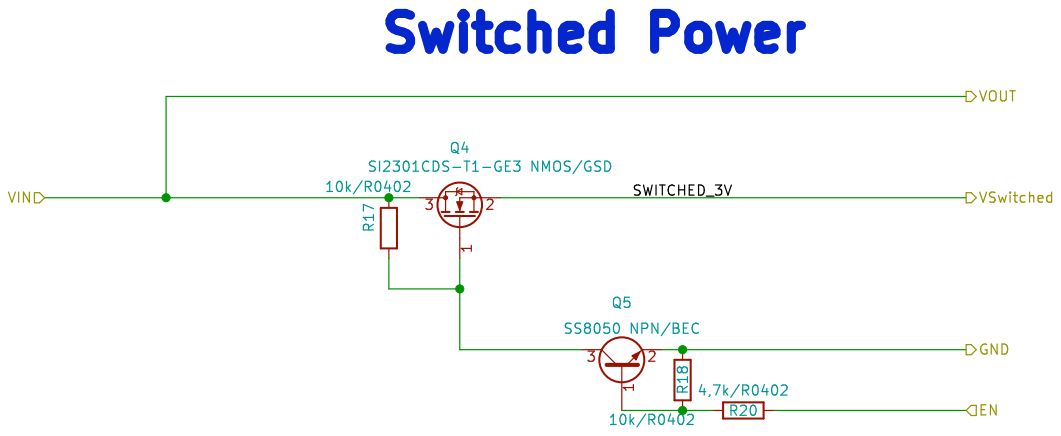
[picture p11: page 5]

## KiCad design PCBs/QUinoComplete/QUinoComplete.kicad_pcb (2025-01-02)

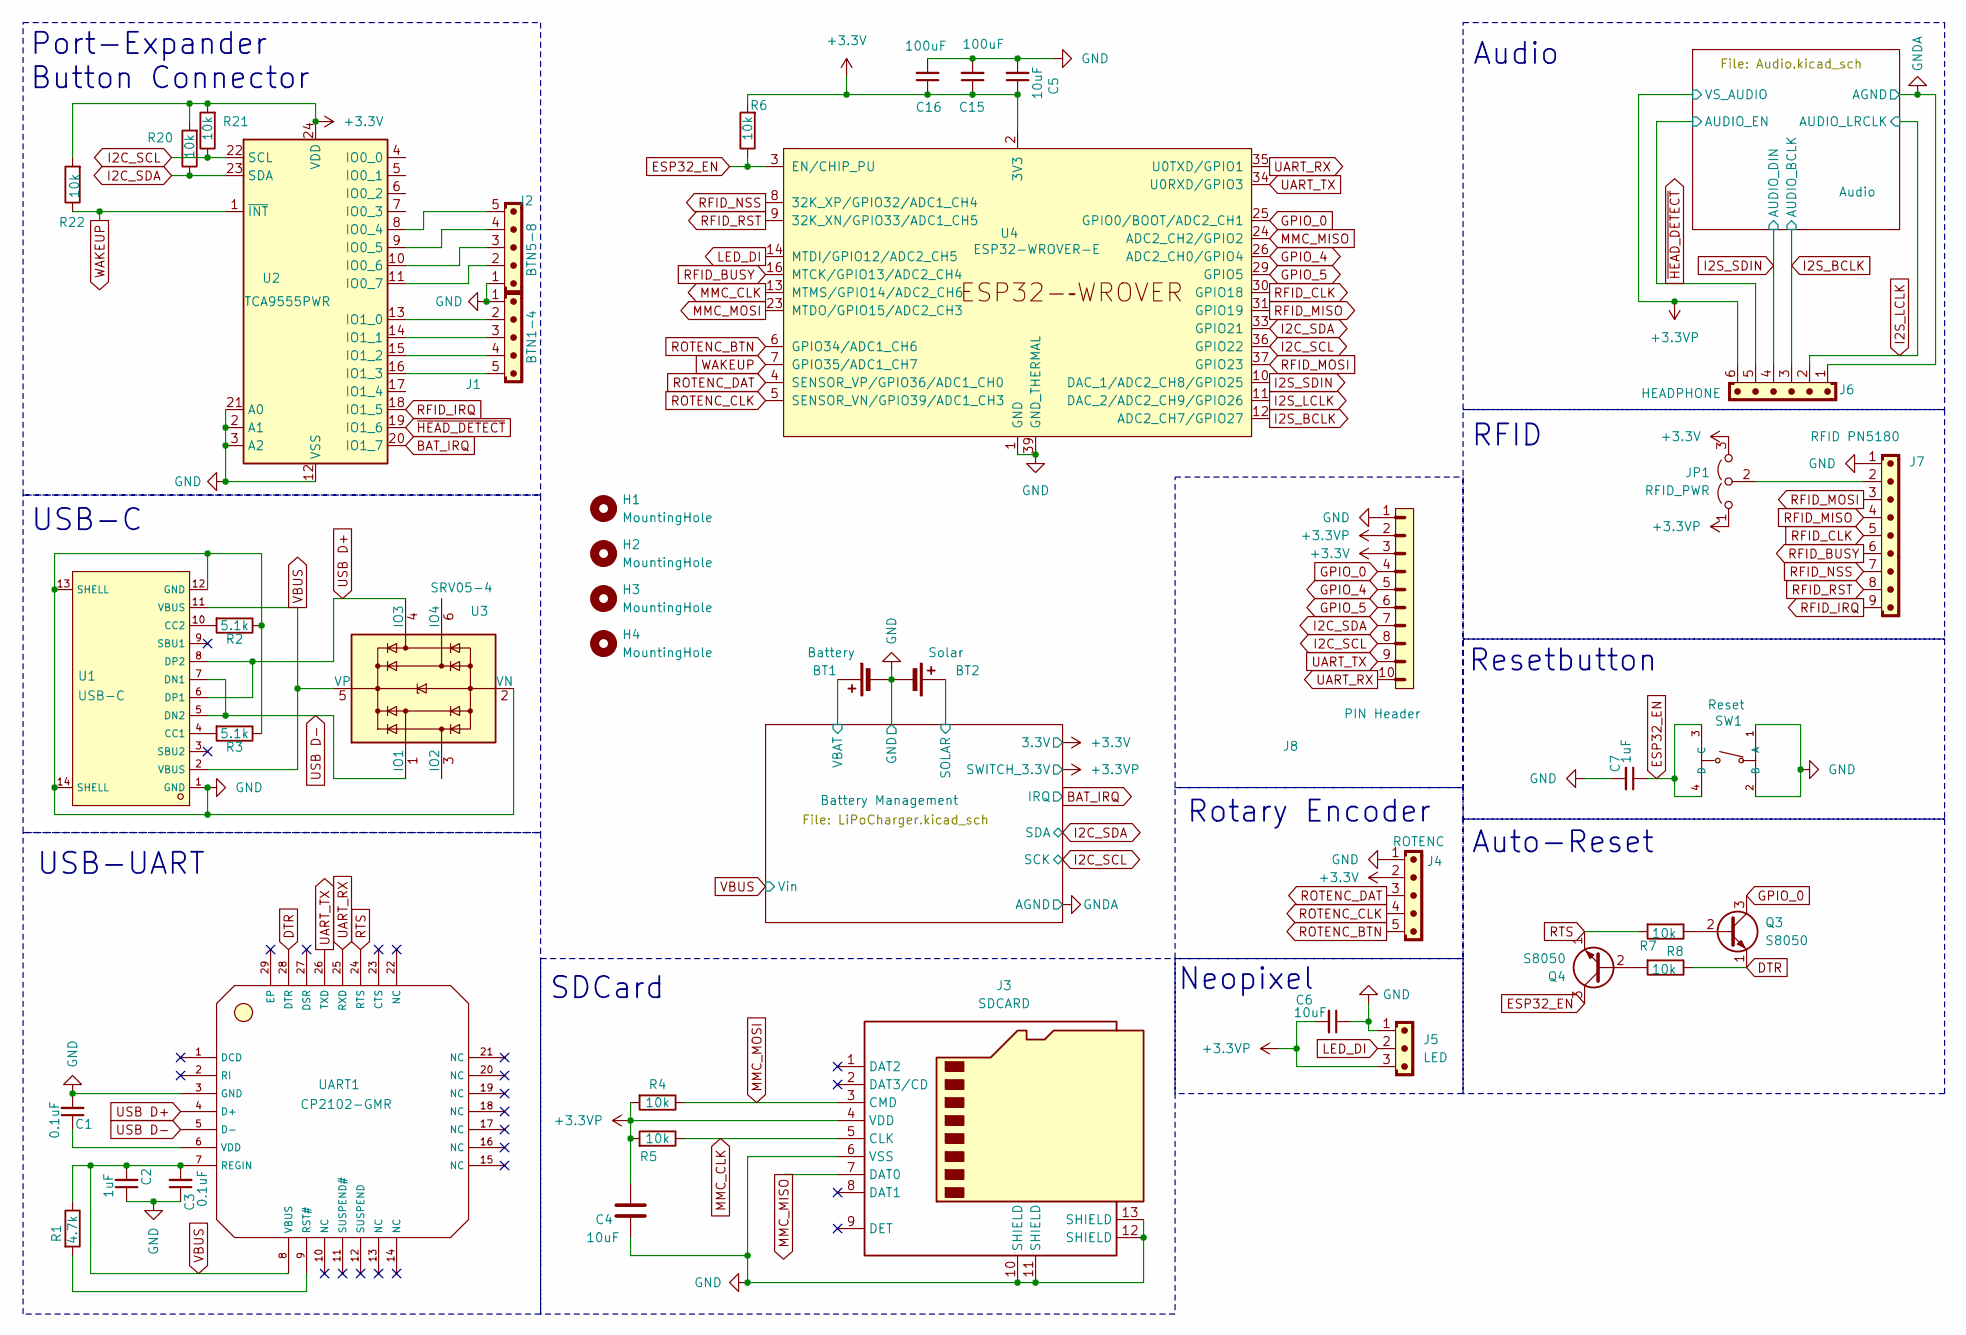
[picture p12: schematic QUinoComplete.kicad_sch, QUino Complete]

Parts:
BT1: Battery; JST_PH_B2B-PH-K_1x02_P2.00mm_Vertical_Reverse
BT2: Solar; JST_PH_B2B-PH-K_1x02_P2.00mm_Vertical_Reverse
C1, C3: 0.1uF; C_0402_1005Metric; JLCB-Basic 1
C2, C7: 1uF; C_0603_1608Metric; JLCB-Basic 1
C4, C5, C6: 10uF; C_0603_1608Metric; JLCB-Basic 1
C15, C16: 100uF; C_1206_3216Metric; JLCB-Basic 1
H1, H2, H3, H4: MountingHole; MountingHole_2.2mm_M2_DIN965
J1: BTN1-4; JST_EH_B5B-EH-A_1x05_P2.50mm_Vertical
J2: BTN5-8; JST_EH_B5B-EH-A_1x05_P2.50mm_Vertical
J3: SDCARD; TF-SMD_TF-CARD-H1.8; JLCB-Basic 0
J4: ROTENC; JST_EH_B5B-EH-A_1x05_P2.50mm_Vertical
J5: LED; JST_EH_B3B-EH-A_1x03_P2.50mm_Vertical
J6: HEADPHONE; JST_EH_B6B-EH-A_1x06_P2.50mm_Vertical
J7: RFID PN5180; JST_EH_B9B-EH-A_1x09_P2.50mm_Vertical
J8: PIN Header; PinHeader_1x10_P2.54mm_Vertical
JP1: RFID_PWR; SolderJumper-3_P1.3mm_Open_RoundedPad1.0x1.5mm_NumberLabels
Q3, Q4: S8050; SOT-23; LCSC C2146
R1: 4.7k; R_0603_1608Metric; LCSC C23162
R2, R3: 5.1k; R_0805_2012Metric; JLCB-Basic 1
R4, R5: 10k; R_0402_1005Metric; JLCB-Basic 1
R6, R7, R8, R20, R21, R22: 10k; R_0402_1005Metric; LCSC C25744
SW1: Reset; SW-SMD_4P-L5.1-W5.1-P3.70-LS6.5-TL_H1.5; LCSC C318884
U1: USB-C; USB-C-SMD_TYPE-C-6PIN-2MD-073; LCSC C2765186
U2: TCA9555PWR; TSSOP-24_4.4x7.8mm_P0.65mm; JLCB-Basic 0
U3: SRV05-4; SOT-23-6; LCSC C7420376
U4: ESP32-WROVER-E; LCSC C2913202
UART1: CP2102-GMR; WQFN-28_L5.0-W5.0-P0.50-BL-EP3.2; LCSC C6568

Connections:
+3.3V: C5.1, C15.1, C16.1, J4.2, J8.3, JP1.3 (B), R6.2, R20.2, R21.2, R22.2, U2.24 (VDD), U4.2 (3V3); also elsewhere on the board
+3.3VP: C4.1, C6.2, J3.4 (VDD), J5.3, J6.6, J8.2, JP1.1 (A), R4.2, R5.2; also elsewhere on the board
/Battery Management/SOLAR: BT2.1 (+); also elsewhere on the board
/Battery Management/VBAT: BT1.1 (+); also elsewhere on the board
BAT_IRQ: U2.20 (IO1_7); also elsewhere on the board
DTR: Q3.1 (E), R8.1, UART1.28 (DTR)
ESP32_EN: C7.1, Q4.3 (C), R6.1, SW1.3 (C), SW1.4 (D), U4.3 (EN/CHIP_PU)
GND: BT1.2 (-), BT2.2 (-), C1.2, C2.1, C3.1, C4.2, C5.2, C6.1, C7.2, C15.2, C16.2, J1.1, J2.1, J3.6 (VSS), J3.10 (SHIELD), J3.11 (SHIELD), J3.12 (SHIELD), J3.13 (SHIELD), J4.1, J5.1, J7.1, J8.1, R2.1, R3.1, SW1.1 (A), SW1.2 (B), U1.1 (GND), U1.12 (GND), U1.13 (SHELL), U1.14 (SHELL), U2.2 (A1), U2.3 (A2), U2.12 (VSS), U2.21 (A0), U3.2 (VN), U4.1 (GND), U4.15 (GND), U4.38 (GND), U4.39 (GND_THERMAL), UART1.3 (GND); also elsewhere on the board
GNDA: J6.1; also elsewhere on the board
GPIO_0: J8.4, Q3.3 (C), U4.25 (GPIO0/BOOT/ADC2_CH1)
GPIO_4: J8.5, U4.26 (ADC2_CH0/GPIO4)
GPIO_5: J8.6, U4.29 (GPIO5)
I2C_SCL: J8.8, R21.1, U2.22 (SCL), U4.36 (GPIO22); also elsewhere on the board
I2C_SDA: J8.7, R20.1, U2.23 (SDA), U4.33 (GPIO21); also elsewhere on the board
I2S_BCLK: J6.3, U4.12 (ADC2_CH7/GPIO27); also elsewhere on the board
I2S_LCLK: J6.2, U4.11 (DAC_2/ADC2_CH9/GPIO26); also elsewhere on the board
I2S_SDIN: J6.4, U4.10 (DAC_1/ADC2_CH8/GPIO25); also elsewhere on the board
LED_DI: J5.2, U4.14 (MTDI/GPIO12/ADC2_CH5)
MMC_CLK: J3.5 (CLK), R5.1, U4.13 (MTMS/GPIO14/ADC2_CH6)
MMC_MISO: J3.7 (DAT0), U4.24 (ADC2_CH2/GPIO2)
MMC_MOSI: J3.3 (CMD), R4.1, U4.23 (MTDO/GPIO15/ADC2_CH3)
unnamed: J7.2, JP1.2 (C)
unnamed: Q3.2 (B), R7.1
unnamed: Q4.2 (B), R8.2
unnamed: R3.2, U1.4 (CC1)
unnamed: R2.2, U1.10 (CC2)
unnamed: J2.5, U2.8 (IO0_4)
unnamed: J2.4, U2.9 (IO0_5)
unnamed: J2.3, U2.10 (IO0_6)
unnamed: J2.2, U2.11 (IO0_7)
unnamed: J1.2, U2.13 (IO1_0)
unnamed: J1.3, U2.14 (IO1_1)
unnamed: J1.4, U2.15 (IO1_2)
unnamed: J1.5, U2.16 (IO1_3)
unnamed: R1.2, UART1.9 (RST#)
unnamed: C1.1, UART1.6 (VDD)
RFID_BUSY: J7.6, U4.16 (MTCK/GPIO13/ADC2_CH4)
RFID_CLK: J7.5, U4.30 (GPIO18)
RFID_IRQ: J7.9, U2.18 (IO1_5)
RFID_MISO: J7.4, U4.31 (GPIO19)
RFID_MOSI: J7.3, U4.37 (GPIO23)
RFID_NSS: J7.7, U4.8 (32K_XP/GPIO32/ADC1_CH4)
RFID_RST: J7.8, U4.9 (32K_XN/GPIO33/ADC1_CH5)
ROTENC_BTN: J4.5, U4.6 (GPIO34/ADC1_CH6)
ROTENC_CLK: J4.4, U4.5 (SENSOR_VN/GPIO39/ADC1_CH3)
ROTENC_DAT: J4.3, U4.4 (SENSOR_VP/GPIO36/ADC1_CH0)
RTS: Q4.1 (E), R7.2, UART1.24 (RTS)
UART_RX: J8.10, U4.35 (U0TXD/GPIO1), UART1.25 (RXD)
UART_TX: J8.9, U4.34 (U0RXD/GPIO3), UART1.26 (TXD)
USB D+: U1.6 (DP1), U1.8 (DP2), U3.4 (IO3), UART1.4 (D+)
USB D-: U1.5 (DN2), U1.7 (DN1), U3.1 (IO1), UART1.5 (D-)
VBUS: C2.2, C3.2, R1.1, U1.2 (VBUS), U1.11 (VBUS), U3.5 (VP), UART1.7 (REGIN), UART1.8 (VBUS); also elsewhere on the board
WAKEUP: R22.1, U2.1 (~INT), U4.7 (GPIO35/ADC1_CH7)
~HEAD_DETECT: J6.5, U2.19 (IO1_6); also elsewhere on the board

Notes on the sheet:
Port-Expander Button Connector
USB-UART
SDCard
RFID
USB-C
Resetbutton
Auto-Reset
Neopixel
Rotary Encoder
Audio

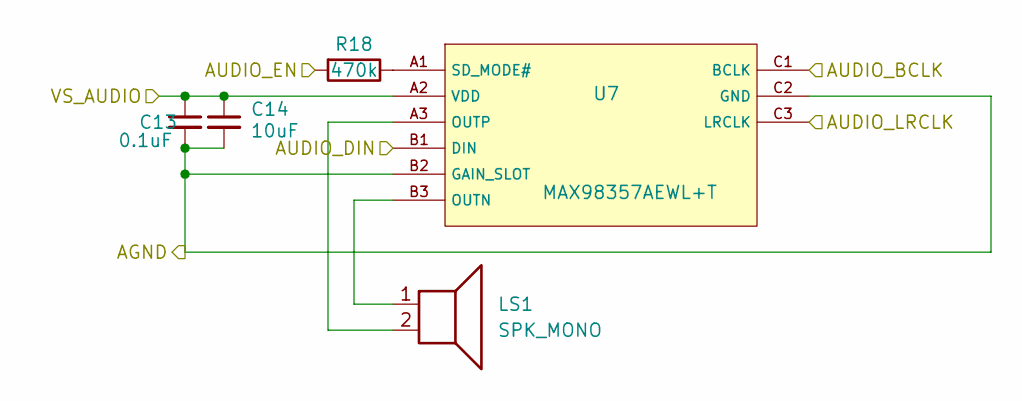
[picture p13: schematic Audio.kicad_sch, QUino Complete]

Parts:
C13: 0.1uF; C_0402_1005Metric; JLCB-Basic 1
C14: 10uF; C_0603_1608Metric; JLCB-Basic 1
LS1: SPK_MONO; JST_EH_B2B-EH-A_1x02_P2.50mm_Vertical
R18: 470k; R_0603_1608Metric; JLCB-Basic 1
U7: MAX98357AEWL+T; WLP-9_L1.4-W1.3-P0.40-R3-C3-BR; LCSC C2682619

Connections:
+3.3VP: C13.1, C14.1, U7.A2 (VDD); also elsewhere on the board
GNDA: C13.2, C14.2, U7.B2 (GAIN_SLOT), U7.C2 (GND); also elsewhere on the board
I2S_BCLK: U7.C1 (BCLK); also elsewhere on the board
I2S_LCLK: U7.C3 (LRCLK); also elsewhere on the board
I2S_SDIN: U7.B1 (DIN); also elsewhere on the board
unnamed: LS1.1, U7.B3 (OUTN)
unnamed: LS1.2, U7.A3 (OUTP)
unnamed: R18.1, U7.A1 (SD_MODE#)
~HEAD_DETECT: R18.2; also elsewhere on the board

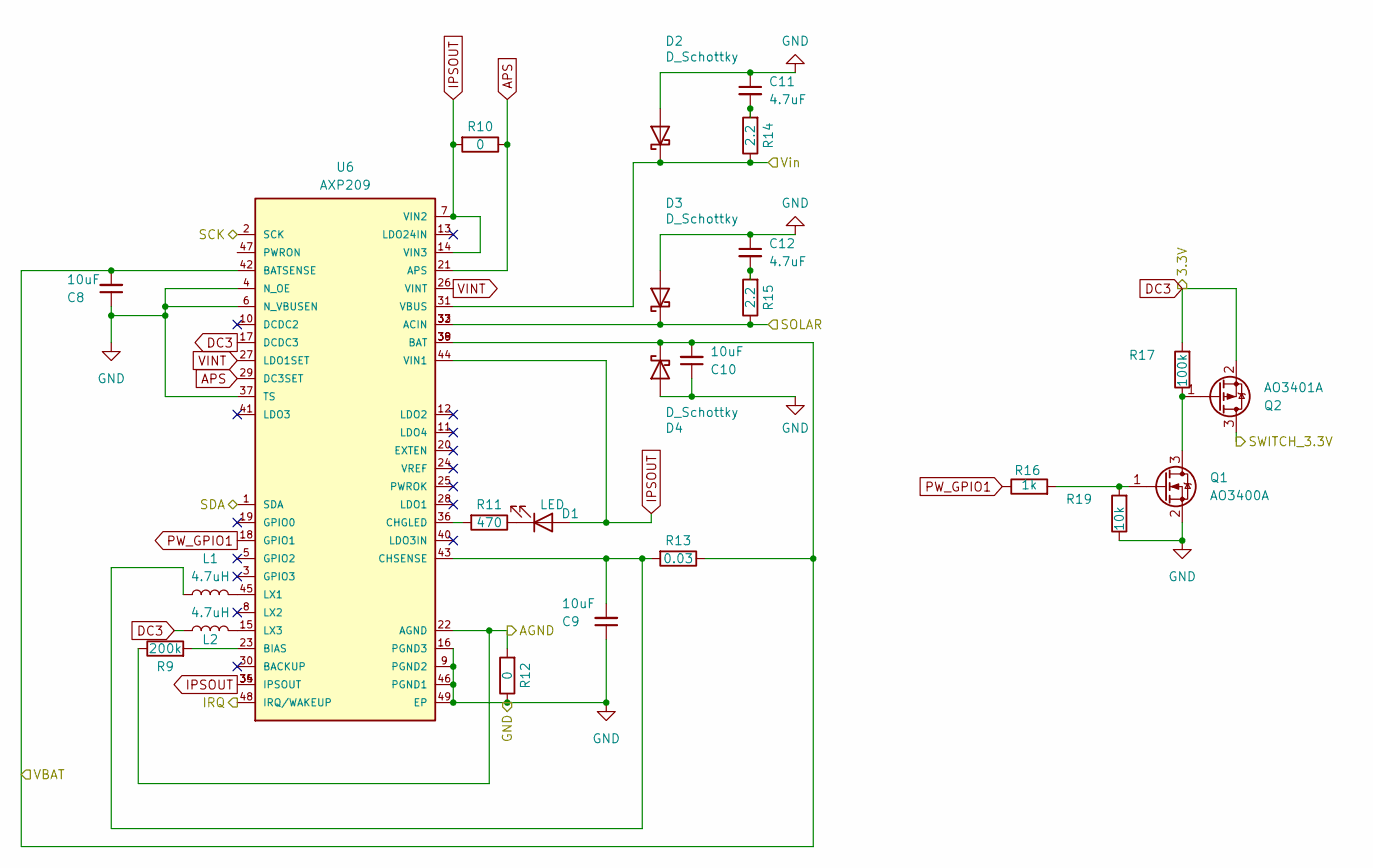
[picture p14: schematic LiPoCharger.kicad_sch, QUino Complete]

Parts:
C8, C9, C10: 10uF; C_0603_1608Metric; JLCB-Basic 1
C11, C12: 4.7uF; C_0402_1005Metric; JLCB-Basic 1
D1: LED; D_0603_1608Metric; JLCB-Basic 1
D2, D3, D4: D_Schottky; D_SMA; JLCB-Basic 1
L1, L2: 4.7uH; IND-SMD_L2.5-W2.0-VLS252012CX-150M; JLCB-Basic 0
Q1: AO3400A; SOT-23; LCSC C20917
Q2: AO3401A; SOT-23; LCSC C15127
R9: 200k; R_0402_1005Metric; JLCB-Basic 1
R10, R12: 0; R_1206_3216Metric; JLCB-Basic 1
R11: 470; R_0402_1005Metric; JLCB-Basic 1
R13: 0.03; R_0805_2012Metric; JLCB-Basic 0
R14, R15: 2.2; R_0603_1608Metric; JLCB-Basic 1
R16: 1k; R_0402_1005Metric; LCSC C11702
R17: 100k; R_0402_1005Metric; LCSC C25741
R19: 10k; R_0402_1005Metric; LCSC C25744
U6: AXP209; QFN40P600X600X80-49N; LCSC C2997895

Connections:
+3.3V: L2.1, Q2.2 (S), R17.2, U6.17 (DCDC3); also elsewhere on the board
+3.3VP: Q2.3 (D); also elsewhere on the board
/Battery Management/SOLAR: D3.1 (K), R15.1, U6.32 (ACIN), U6.33 (ACIN); also elsewhere on the board
/Battery Management/VBAT: C8.2, C10.2, D4.1 (K), R13.1, U6.38 (BAT), U6.39 (BAT), U6.42 (BATSENSE); also elsewhere on the board
APS: R10.1, U6.21 (APS), U6.29 (DC3SET)
BAT_IRQ: U6.48 (IRQ/WAKEUP); also elsewhere on the board
GND: C8.1, C9.1, C10.1, C11.1, C12.1, D2.2 (A), D3.2 (A), D4.2 (A), Q1.2 (S), R12.1, R19.1, U6.4 (N_OE), U6.6 (N_VBUSEN), U6.9 (PGND2), U6.16 (PGND3), U6.37 (TS), U6.46 (PGND1), U6.49 (EP); also elsewhere on the board
GNDA: R9.1, R12.2, U6.22 (AGND); also elsewhere on the board
I2C_SCL: U6.2 (SCK); also elsewhere on the board
I2C_SDA: U6.1 (SDA); also elsewhere on the board
IPSOUT: D1.2 (A), R10.2, U6.7 (VIN2), U6.14 (VIN3), U6.34 (IPSOUT), U6.35 (IPSOUT), U6.44 (VIN1)
unnamed: C11.2, R14.2
unnamed: C12.2, R15.2
unnamed: D1.1 (K), R11.1
unnamed: Q1.3 (D), Q2.1 (G), R17.1
unnamed: Q1.1 (G), R16.2, R19.2
unnamed: R9.2, U6.23 (BIAS)
unnamed: R11.2, U6.36 (CHGLED)
unnamed: C9.2, L1.1, R13.2, U6.43 (CHSENSE)
unnamed: L1.2, U6.45 (LX1)
unnamed: L2.2, U6.15 (LX3)
PW_GPIO1: R16.1, U6.18 (GPIO1)
VBUS: D2.1 (K), R14.1, U6.31 (VBUS); also elsewhere on the board
VINT: U6.26 (VINT), U6.27 (LDO1SET)

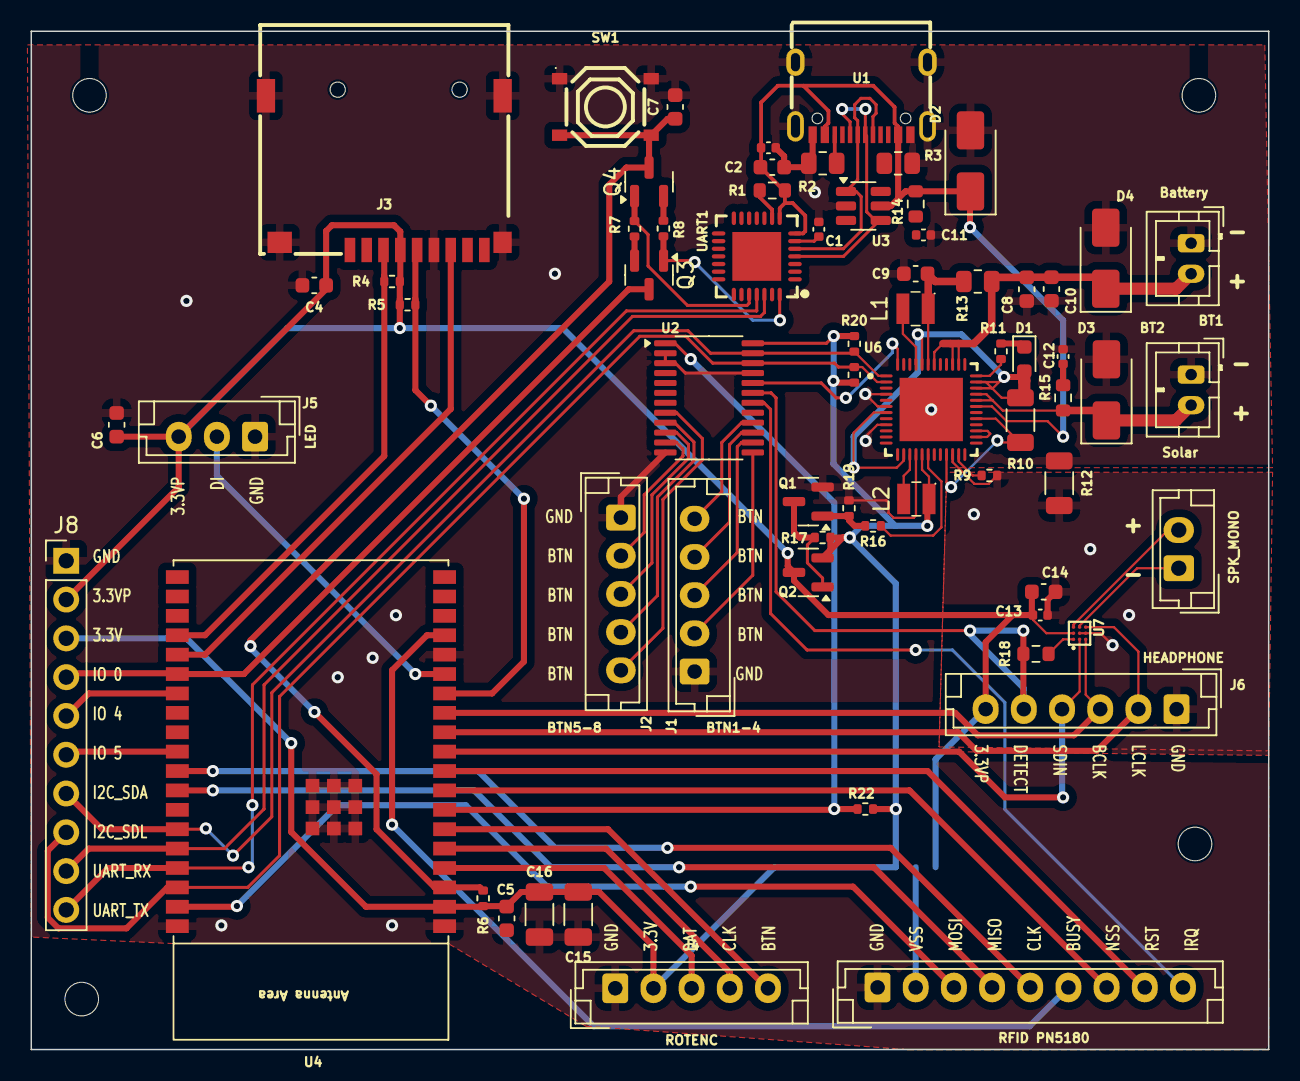
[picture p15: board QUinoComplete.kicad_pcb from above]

Board: 2 copper layers, 81.0 x 66.7 mm, 72 parts (1 on the bottom side), 71 nets.

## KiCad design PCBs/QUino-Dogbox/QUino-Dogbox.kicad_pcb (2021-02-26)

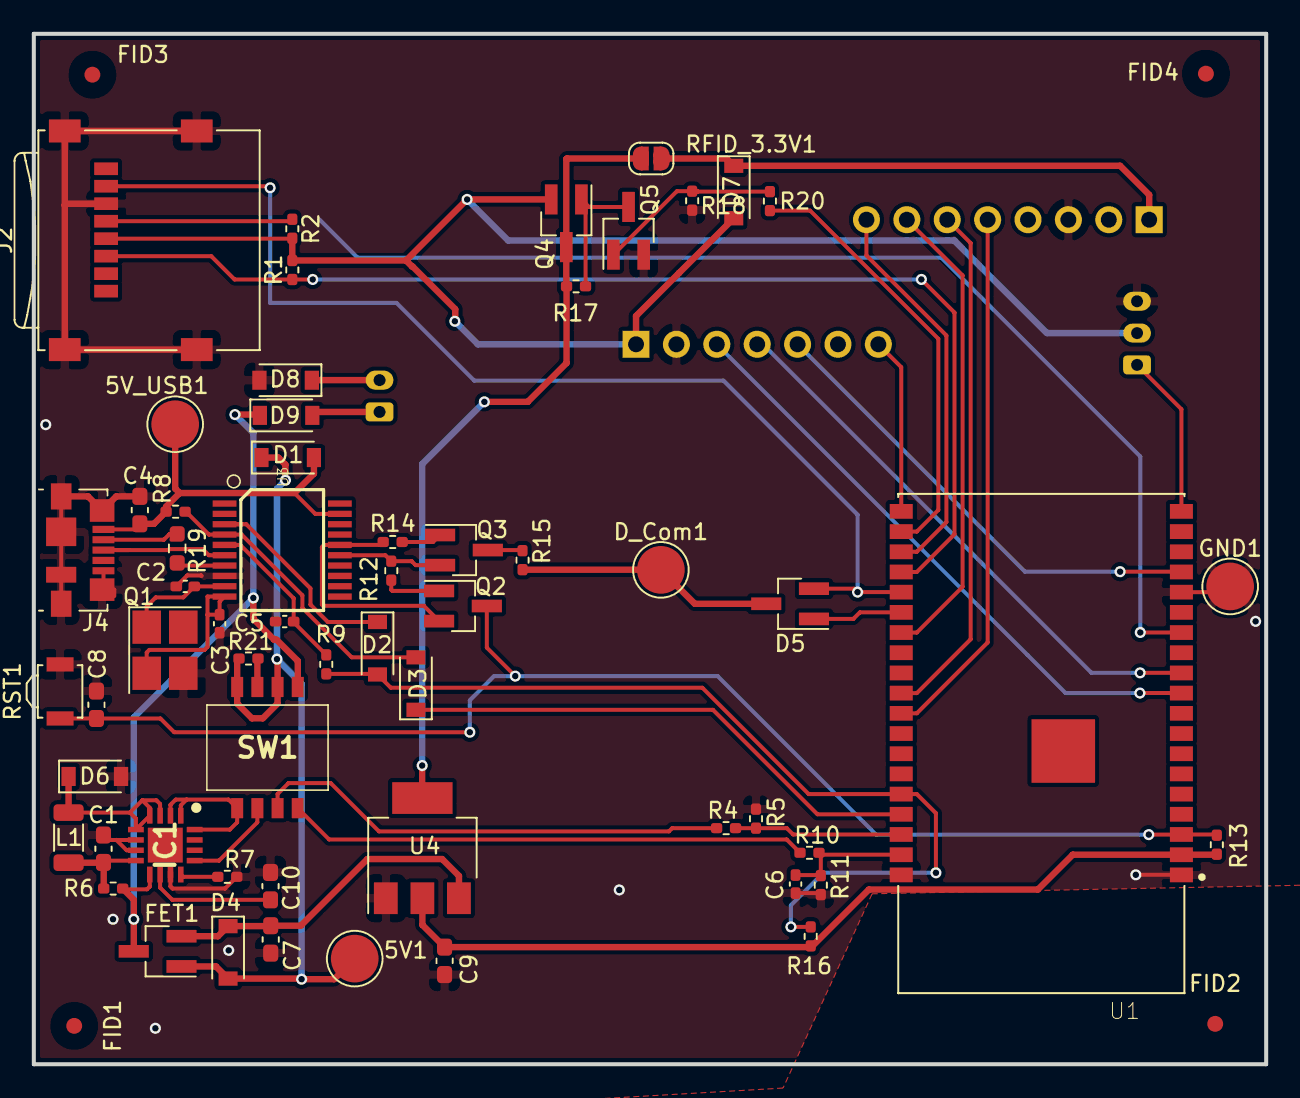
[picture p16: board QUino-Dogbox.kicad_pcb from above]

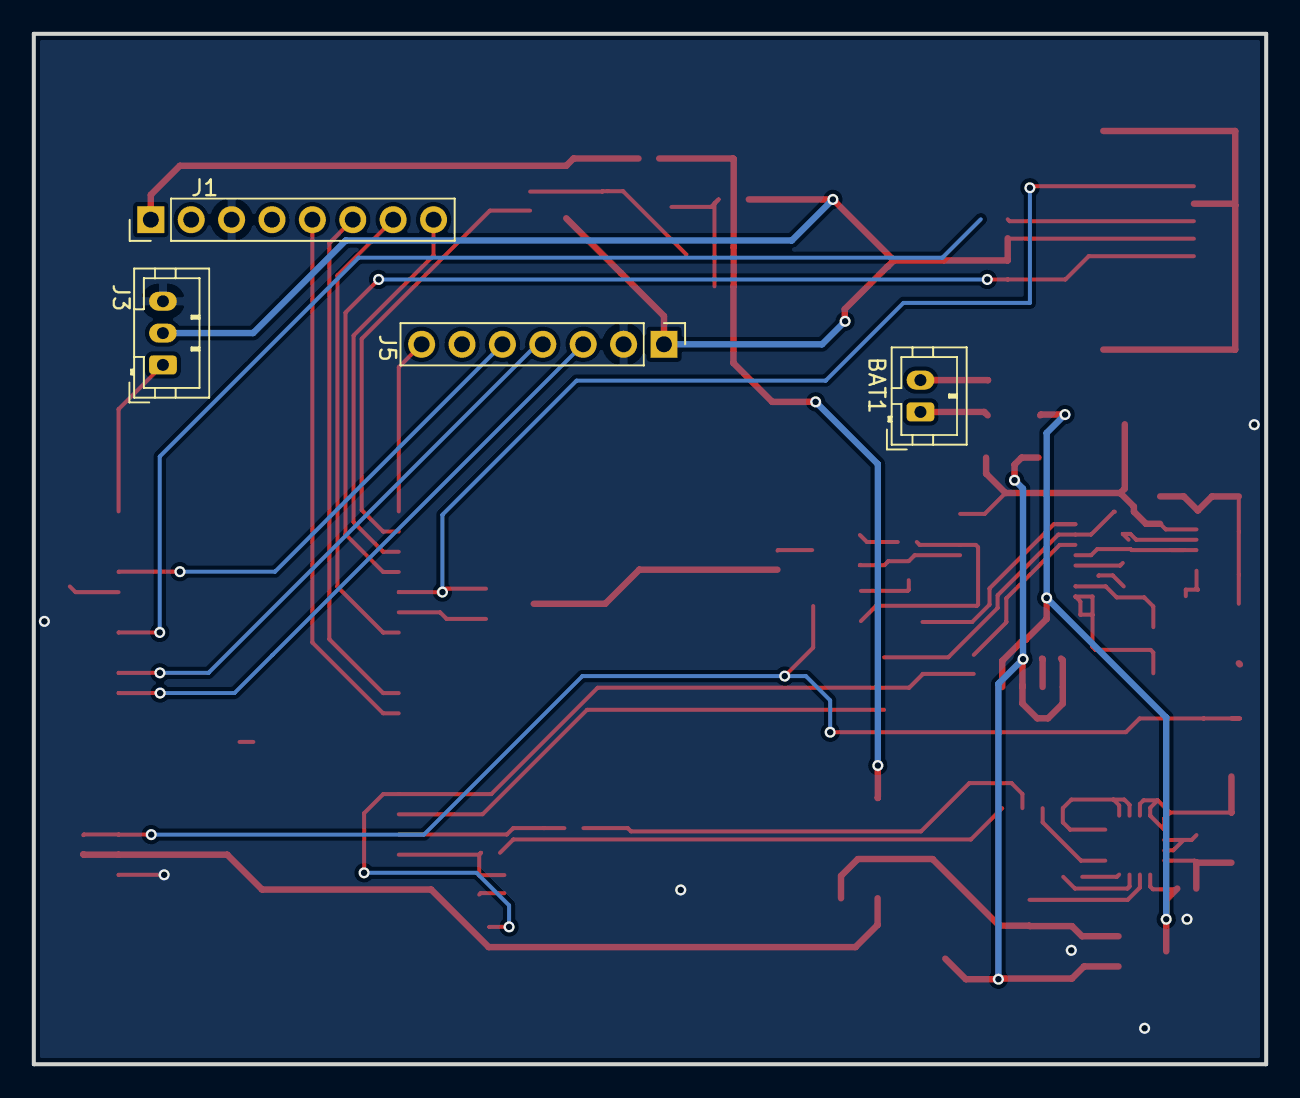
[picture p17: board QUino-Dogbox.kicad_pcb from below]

Board: 2 copper layers, 77.5 x 64.8 mm, 67 parts (4 on the bottom side), 54 nets.

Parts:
5V1, 5V_USB1: TESTPAD; TestPoint_Pad_D3.0mm
BAT1: DW02S; JST_PH_B2B-PH-K_1x02_P2.00mm_Vertical
C1: 10uF/C0603; C_0603_1608Metric_Pad1.08x0.95mm_HandSolder
C2, C3: 27pF/50V/5%/C0G/C0402; C_0402_1005Metric_Pad0.74x0.62mm_HandSolder
C4, C7, C9: 22uF/6.3V/20%/X5R/C0603; C_0603_1608Metric_Pad1.08x0.95mm_HandSolder
C5, C6: 100nF/10V/10%/X7R/C0402; C_0402_1005Metric_Pad0.74x0.62mm_HandSolder
C8: 1uF/10V/10%/X5R/C0603; C_0603_1608Metric_Pad1.08x0.95mm_HandSolder
C10: 0.1uF/C0603; C_0603_1608Metric_Pad1.08x0.95mm_HandSolder
D1, D2, D3, D4, D6, D7, D8, D9: 1N5819W/SOD123; D_SOD-123
D5: BAT54C(SOT23-3); SOT-23_Handsoldering
D_Com1: TESTPAD; TestPoint_Pad_D3.0mm
FET1: WPM2015-3/TR; SOT-23_Handsoldering
FID1, FID2, FID3, FID4: Fiducial; Fiducial_1mm_Mask3mm
GND1: TESTPAD; TestPoint_Pad_D3.0mm
IC1: TP5000-QFN16; QFN65P400X400X90-17N-D
J1: RFID RC522; PinHeader_1x08_P2.54mm_Vertical
J2: Micro_SD_Card; microSD_HC_Wuerth_693072010801
J3: Neopixel; JST_PH_B3B-PH-K_1x03_P2.00mm_Vertical
J4: USB_B_Micro; USB_Micro-B_Molex_47346-0001
J5: Conn_01x07_Male; PinHeader_1x07_P2.54mm_Vertical
L1: 4.7u; L_1206_3216Metric
Q1: Q12MHz/20pF/10ppm/4P/3.2x2.5mm; Crystal_SMD_3225-4Pin_3.2x2.5mm_HandSoldering
Q2, Q3: BC817-40(SOT23); SOT-23_Handsoldering
Q4: SI2302DS NMOS/GSD; SOT-23_Handsoldering
Q5: QBC817 NPN/BEC; SOT-23_Handsoldering
R1, R2, R8, R9, R13, R16, R17, R18, R21: 10k/R0402; R_0402_1005Metric_Pad0.72x0.64mm_HandSolder
R4: 220k/R0402; R_0402_1005Metric_Pad0.72x0.64mm_HandSolder
R5, R10, R11: 470k/R0402; R_0402_1005Metric_Pad0.72x0.64mm_HandSolder
R6, R7, R12, R14: 2.2k/R0402; R_0402_1005Metric_Pad0.72x0.64mm_HandSolder
R15: 220/R0402; R_0402_1005Metric_Pad0.72x0.64mm_HandSolder
R19: 0 /R0402; R_0603_1608Metric_Pad0.98x0.95mm_HandSolder
R20: 4,7k/R0402; R_0402_1005Metric_Pad0.72x0.64mm_HandSolder
RFID_3.3V1: Opened; SolderJumper-2_P1.3mm_Open_RoundedPad1.0x1.5mm
RST1: IT-1185AU2-160G-G-TR; SW_SPST_B3U-3000P
SW1: SW_DIP_x04; DSHP04TSS
U1: ESP32-WROVER; XCVR_ESP32-WROVER-I
U3: CH340T(SSOP20W); SSOP20-0.65-7.6X5.2MM
U4: AMS1117-3.3; SOT-223-3_TabPin2

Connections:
+3V3: C9.1, Q4.3, R13.1, R16.2, R17.2, RFID_3.3V1.1, U1.2, U4.2
+5V: 5V1.1, D1.1, D4.2, FET1.1, R21.1, SW1.2, SW1.4
/LiPoPower/5V: 5V_USB1.1, C4.1, D1.2, J4.1, R8.1, U3.19
/Sheet602F0C3C/D_Com: D5.3, D_Com1.1, R15.2
/Sheet602F0C3C/GPIO_EN: C8.1, Q2.3, R13.2, RST1.1, U1.3
/Sheet602F0C3C/UD+: J4.3, U3.6
/Sheet602F0C3C/UD-: R19.2, U3.7
/VSwitched: D7.2, J2.4, J3.2, J5.1, Q4.2, R1.2, R2.2
DAC_CLK: J5.5, U1.16
EXTPWR_SENSE: R4.1, R5.2, U1.36
GATE_PWR: R20.2, U1.21
GND: C1.2, C2.2, C3.2, C4.2, C5.2, C6.1, C7.2, C8.2, C9.2, C10.1, D6.2, D8.2, GND1.1, IC1.6, IC1.7, IC1.11, J1.3, J2.6, J2.9, J3.3, J4.5, J4.6, J5.2, Q1.3, Q5.2, R5.1, R7.2, R11.2, R18.2, RST1.2, U1.1, U1.15, U1.38, U3.8, U4.1
GPIO25_DAC_1: J5.3, U1.10
GPIO26_DAC_2: J5.4, U1.11
GPIO_0: D5.1, U1.25
GPIO_2: D5.2, J2.7, U1.24
GPIO_14: J2.5, R2.1, U1.13
GPIO_15: J2.3, R1.1, U1.23
GPIO_RX: D2.2, R9.2, R16.1, U1.34
GPIO_TX: D3.1, U1.35
HEADPHONE_JACK: J5.7, U1.20
LED_DI: J3.1, U1.19
unnamed: BAT1.1, D9.2
unnamed: BAT1.2, D8.1
unnamed: C1.1, IC1.8, L1.2, R6.1
unnamed: C2.1, Q1.1, U3.9
unnamed: C3.1, Q1.2, U3.10
unnamed: C5.1, R9.1, U3.5
unnamed: C7.1, D4.1, FET1.2, U4.3
unnamed: C10.2, IC1.10
unnamed: D2.1, U3.3
unnamed: D3.2, R8.2, U3.4
unnamed: D6.1, IC1.3, IC1.4, IC1.5, L1.1
unnamed: D7.1, J1.1, RFID_3.3V1.2
unnamed: IC1.1, IC1.2, IC1.16, SW1.5
unnamed: IC1.12, R7.1
unnamed: IC1.13, SW1.6
unnamed: J4.2, R19.1
unnamed: Q2.1, R12.2
unnamed: Q2.2, R14.1, U3.16
unnamed: Q3.1, R14.2
unnamed: Q3.2, R12.1, U3.15
unnamed: Q3.3, R15.1
unnamed: Q4.1, Q5.3, R17.1
unnamed: Q5.1, R18.1, R20.1
unnamed: R4.2, SW1.7
unnamed: R10.1, SW1.8
unnamed: R21.2, SW1.3
RFID_CLK: J1.7, U1.26
RFID_CS: J1.8, U1.22
RFID_MISO: J1.5, U1.30
RFID_MOSI: J1.6, U1.29
VBAT: D9.1, FET1.3, IC1.9, R6.2, SW1.1
VBAT_MEASURE: C6.2, R10.2, R11.1, U1.37

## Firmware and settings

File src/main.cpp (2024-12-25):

// !!! MAKE SURE TO EDIT settings.h !!!
#include <Arduino.h>
#include "settings.h" // Contains all user-relevant settings (general)

#include "main.h"

#include "AudioPlayer.h"
#include "Battery.h"
#include "Bluetooth.h"
#include "Button.h"
#include "Cloud.h"
#include "Cmd.h"
#include "Common.h"
#include "Ftp.h"
#include "HallEffectSensor.h"
#include "IrReceiver.h"
#include "Led.h"
#include "Log.h"
#include "MemX.h"
#include "Mqtt.h"
#include "Port.h"
#include "Power.h"
#include "Queues.h"
#include "Rfid.h"
#include "RotaryEncoder.h"
#include "SdCard.h"
#include "System.h"
#include "Web.h"
#include "Wlan.h"
#include "revision.h"

#include <Wire.h>

bool gPlayLastRfIdWhenWiFiConnected = false;
bool gTriedToConnectToHost = false;

static constexpr const char *logo = R"literal(
 _____   ____    ____            _
| ____| / ___|  |  _ \   _   _  (_)  _ __     ___
|  _|   \__  \  | |_) | | | | | | | | '_ \   / _ \
| |___   ___) | |  __/  | |_| | | | | | | | | (_) |
|_____| |____/  |_|      \__,_| |_| |_| |_|  \___/
         Rfid-controlled musicplayer


)literal";

// avoid PSRAM check while wake-up from deepsleep
bool testSPIRAM(void) {
	return true;
}

#ifdef PLAY_LAST_RFID_AFTER_REBOOT
bool recoverLastRfid = true;
bool recoverBootCount = true;
bool resetBootCount = false;
uint32_t bootCount = 0;
#endif

////////////

// I2C
#ifdef I2C_2_ENABLE
TwoWire i2cBusTwo = TwoWire(1);
#endif

#ifdef PLAY_LAST_RFID_AFTER_REBOOT
// If a problem occurs, remembering last rfid can lead into a boot loop that's hard to escape of.
// That reason for a mechanism is necessary to prevent this.
// At start of a boot, bootCount is incremented by one and after 30s decremented because
// uptime of 30s is considered as "successful boot".
void recoverBootCountFromNvs(void) {
	if (recoverBootCount) {
		recoverBootCount = false;
		resetBootCount = true;
		bootCount = gPrefsSettings.getUInt("bootCount", 999);

		if (bootCount == 999) { // first init
			bootCount = 1;
			gPrefsSettings.putUInt("bootCount", bootCount);
		} else if (bootCount >= 3) { // considered being a bootloop => don't recover last rfid!
			bootCount = 1;
			gPrefsSettings.putUInt("bootCount", bootCount);
			gPrefsSettings.putString("lastRfid", "-1"); // reset last rfid
			Log_Println(bootLoopDetected, LOGLEVEL_ERROR);
			recoverLastRfid = false;
		} else { // normal operation
			gPrefsSettings.putUInt("bootCount", ++bootCount);
		}
	}

	if (resetBootCount && millis() >= 30000) { // reset bootcount
		resetBootCount = false;
		bootCount = 0;
		gPrefsSettings.putUInt("bootCount", bootCount);
		Log_Println(noBootLoopDetected, LOGLEVEL_INFO);
	}
}

// Get last RFID-tag applied from NVS
void recoverLastRfidPlayedFromNvs(bool force) {
	if (recoverLastRfid || force) {
		if (System_GetOperationMode() == OPMODE_BLUETOOTH_SINK) { // Don't recover if BT-mode is desired
			recoverLastRfid = false;
			return;
		}
		recoverLastRfid = false;
		String lastRfidPlayed = gPrefsSettings.getString("lastRfid", "-1");
		if (!lastRfidPlayed.compareTo("-1")) {
			Log_Println(unableToRestoreLastRfidFromNVS, LOGLEVEL_INFO);
		} else {
			xQueueSend(gRfidCardQueue, lastRfidPlayed.c_str(), 0);
			gPlayLastRfIdWhenWiFiConnected = !force;
			Log_Printf(LOGLEVEL_INFO, restoredLastRfidFromNVS, lastRfidPlayed.c_str());
		}
	}
}
#endif

void setup() {
	Log_Init();
	Queues_Init();

	// Make sure all wakeups can be enabled *before* initializing RFID, which can enter sleep immediately
	Button_Init(); // To preseed internal button-storage with values

#ifdef PN5180_ENABLE_LPCD
	System_Init_LPCD();
	Rfid_Init();
#endif

	System_Init();

// Init 2nd i2c-bus if RC522 is used with i2c or if port-expander is enabled
#ifdef I2C_2_ENABLE
	i2cBusTwo.begin(ext_IIC_DATA, ext_IIC_CLK);
	delay(50);
	Log_Println(rfidScannerReady, LOGLEVEL_DEBUG);
#endif

#ifdef HALLEFFECT_SENSOR_ENABLE
	gHallEffectSensor.init();
#endif

	// Needs i2c first if port-expander is used
	Port_Init();

	// If port-expander is used, port_init has to be called first, as power can be (possibly) done by port-expander
	Power_Init();

	Battery_Init();

	// Init audio before power on to avoid speaker noise
	AudioPlayer_Init();

	// All checks that could send us to sleep are done, power up fully
	Power_PeripheralOn();

	Led_Init();

	// Needs power first
	SdCard_Init();

	// welcome message
	Serial.print(logo);

	// Software-version
	Log_Println(softwareRevision, LOGLEVEL_NOTICE);
	Log_Println(gitRevision, LOGLEVEL_NOTICE);
	Log_Printf(LOGLEVEL_NOTICE, "Arduino version: %d.%d.%d", ESP_ARDUINO_VERSION_MAJOR, ESP_ARDUINO_VERSION_MINOR, ESP_ARDUINO_VERSION_PATCH);
	Log_Printf(LOGLEVEL_NOTICE, "ESP-IDF version: %s", ESP.getSdkVersion());

	// print wake-up reason
	System_ShowWakeUpReason();
	// print SD card info
	SdCard_PrintInfo();

	Cloud_Init();
	Ftp_Init();
	Mqtt_Init();
#ifndef PN5180_ENABLE_LPCD
	#if defined(RFID_READER_TYPE_MFRC522_SPI) || defined(RFID_READER_TYPE_MFRC522_I2C) || defined(RFID_READER_TYPE_PN5180)
	Rfid_Init();
	#endif
#endif
	RotaryEncoder_Init();
	Wlan_Init();
	Bluetooth_Init();

	if (OPMODE_NORMAL == System_GetOperationMode()) {
		Wlan_Cyclic();
	}

	IrReceiver_Init();
	System_UpdateActivityTimer(); // initial set after boot
	Led_Indicate(LedIndicatorType::BootComplete);

	Log_Printf(LOGLEVEL_DEBUG, "%s: %u", freeHeapAfterSetup, ESP.getFreeHeap());
	if (psramFound()) {
		Log_Printf(LOGLEVEL_DEBUG, "PSRAM: %u bytes", ESP.getPsramSize());
	} else {
		Log_Println("PSRAM: --", LOGLEVEL_DEBUG);
	}
	Log_Printf(LOGLEVEL_DEBUG, "Flash-size: %u bytes", ESP.getFlashChipSize());

	// setup timezone & show internal RTC date/time if available
	setenv("TZ", timeZone, 1);
	tzset();
	struct tm timeinfo;
	if (getLocalTime(&timeinfo, 5)) {
		static char timeStringBuff[255];
		snprintf(timeStringBuff, sizeof(timeStringBuff), dateTimeRTC, timeinfo.tm_mday, timeinfo.tm_mon + 1, timeinfo.tm_year + 1900, timeinfo.tm_hour, timeinfo.tm_min, timeinfo.tm_sec);
		Log_Println(timeStringBuff, LOGLEVEL_DEBUG);
	}

	if (Wlan_IsConnected()) {
		Log_Printf(LOGLEVEL_DEBUG, "RSSI: %d dBm", Wlan_GetRssi());
	}

#ifdef CONTROLS_LOCKED_BY_DEFAULT
	System_SetLockControls(true);
#endif
}

void loop() {
	if (OPMODE_BLUETOOTH_SINK == System_GetOperationMode()) {
		// bluetooth speaker mode
		Bluetooth_Cyclic();
	} else if (OPMODE_BLUETOOTH_SOURCE == System_GetOperationMode()) {
		// bluetooth headset mode
		Bluetooth_Cyclic();
		RotaryEncoder_Cyclic();
	} else {
		// normal mode
		Wlan_Cyclic();
		Web_Cyclic();
		Ftp_Cyclic();
		RotaryEncoder_Cyclic();
		Mqtt_Cyclic();
	}
	vTaskDelay(portTICK_PERIOD_MS * 1u);
	AudioPlayer_Cyclic();
	vTaskDelay(portTICK_PERIOD_MS * 1u);
	Battery_Cyclic();
	// Port_Cyclic(); // called by button (controlled via hw-timer)
	Button_Cyclic();
	vTaskDelay(portTICK_PERIOD_MS * 1u);
	System_Cyclic();
	Rfid_PreferenceLookupHandler();

#ifdef PLAY_LAST_RFID_AFTER_REBOOT
	recoverBootCountFromNvs();
	recoverLastRfidPlayedFromNvs();
#endif

	IrReceiver_Cyclic();
	vTaskDelay(portTICK_PERIOD_MS * 2u);

#ifdef HALLEFFECT_SENSOR_ENABLE
	gHallEffectSensor.cyclic();
#endif
}

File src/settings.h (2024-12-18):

// clang-format off

#ifndef __ESPUINO_SETTINGS_H__
    	#define __ESPUINO_SETTINGS_H__
        #include "Arduino.h"
        #include "values.h"
#if __has_include("settings-override.h")
    	#include "settings-override.h"
#else
	//######################### INFOS ####################################
	// This is the general configfile for ESPuino-configuration.

	//################## HARDWARE-PLATFORM ###############################
	/* Make sure to also edit the configfile, that is specific for your platform.
	If in doubts (your develboard is not listed) use HAL 7

	!!!Only ESP32 with PSRAM are supported!!!

	1: Wemos Lolin32                        => REMOVED (because of missing PSRAM)
	2: ESP32-A1S Audiokit                   => REMOVED (because of stale development, lack of users and lack of GPIOs)
	3: Wemos Lolin D32                      => REMOVED (because of missing PSRAM)
	4: Wemos Lolin D32 pro                  => settings-lolin_D32_pro.h
	5: Lilygo T8 (V1.7)                     => settings-ttgo_t8.h
	6: ESPuino complete                     => settings-complete.h
	7: Lolin D32 pro SDMMC Port-Expander    => settings-lolin_d32_pro_sdmmc_pe.h
	8: AZDelivery ESP32 NodeMCU             => REMOVED (because of missing PSRAM)
	9: Lolin D32 SDMMC Port-Expander        => REMOVED (because of missing PSRAM)
	99: custom                              => settings-custom.h
	*/
	#ifndef HAL             // Will be set by platformio.ini. There's no need to adjust this manually right here
		#define HAL 7
	#endif


	//########################## MODULES #################################
	//#define PORT_EXPANDER_ENABLE          // When enabled, buttons can be connected via port-expander PCA9555 (https://forum.espuino.de/t/einsatz-des-port-expanders-pca9555/306)
	//#define I2S_COMM_FMT_LSB_ENABLE       // Enables FMT instead of MSB for I2S-communication-format. Used e.g. by PT2811. Don't enable for MAX98357a, AC101 or PCM5102A)
	#define MDNS_ENABLE                     // When enabled, you don't have to handle with ESPuino's IP-address. If hostname is set to "ESPuino", you can reach it via ESPuino.local
	//#define MQTT_ENABLE                   // Make sure to configure mqtt-server and (optionally) username+pwd
	#define FTP_ENABLE                      // Enables FTP-server; DON'T FORGET TO ACTIVATE AFTER BOOT BY PRESSING PAUSE + NEXT-BUTTONS (IN PARALLEL)!
	#define NEOPIXEL_ENABLE                 // Don't forget configuration of NUM_LEDS if enabled
	//#define NEOPIXEL_REVERSE_ROTATION     // Some Neopixels are adressed/soldered counter-clockwise. This can be configured here.
	#define LANGUAGE DE                     // DE = deutsch; EN = english
	//#define STATIC_IP_ENABLE              // DEPRECATED: Enables static IP-configuration (change static ip-section accordingly)
	#define HEADPHONE_ADJUST_ENABLE         // Used to adjust (lower) volume for optional headphone-pcb (refer maxVolumeSpeaker / maxVolumeHeadphone) and to enable stereo (if PLAY_MONO_SPEAKER is set)
	//#define PLAY_MONO_SPEAKER             // If only one speaker is used enabling mono should make sense. Please note: headphones is always stereo (if HEADPHONE_ADJUST_ENABLE is active)
	#define SHUTDOWN_IF_SD_BOOT_FAILS       // Will put ESP to deepsleep if boot fails due to SD. Really recommend this if there's in battery-mode no other way to restart ESP! Interval adjustable via deepsleepTimeAfterBootFails.
	#define MEASURE_BATTERY_VOLTAGE         // Enables battery-measurement via GPIO (ADC) and voltage-divider
	//#define MEASURE_BATTERY_MAX17055      // Enables battery-measurement via external fuel gauge (MAX17055)
	//#define SHUTDOWN_ON_BAT_CRITICAL      // Whether to turn off on critical battery-level (only used if MEASURE_BATTERY_XXX is active)
	//#define PLAY_LAST_RFID_AFTER_REBOOT   // When restarting ESPuino, the last RFID that was active before, is recalled and played
	#define USEROTARY_ENABLE                // If rotary-encoder is used (don't forget to review WAKEUP_BUTTON if you disable this feature!)
	//#define BLUETOOTH_ENABLE                // If enabled and bluetooth-mode is active, you can stream to your ESPuino or to a headset via bluetooth (a2dp-sink & a2dp-source). Note: This feature consumes a lot of resources and the available flash/ram might not be sufficient.
	//#define IR_CONTROL_ENABLE             // Enables remote control (https://forum.espuino.de/t/neues-feature-fernsteuerung-per-infrarot-fernbedienung/265)
	//#define PAUSE_WHEN_RFID_REMOVED       // Playback starts when card is applied and pauses automatically, when card is removed (https://forum.espuino.de/t/neues-feature-pausieren-wenn-rfid-karte-entfernt-wurde/541)
	//#define DONT_ACCEPT_SAME_RFID_TWICE   // RFID-reader doesn't accept the same RFID-tag twice in a row (unless it's a modification-card or RFID-tag is unknown in NVS). Flag will be ignored silently if PAUSE_WHEN_RFID_REMOVED is active. (https://forum.espuino.de/t/neues-feature-dont-accept-same-rfid-twice/1247)
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

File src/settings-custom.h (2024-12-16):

// clang-format off

#ifndef __ESPUINO_SETTINGS_CUSTOM_H__
#define __ESPUINO_SETTINGS_CUSTOM_H__
    #include "Arduino.h"

    //######################### INFOS ####################################
    /* This is not a develboard-specific config-file. It's intended for your own use.
    It's been originally derived from lolin32, but just change it according your needs!
    */

    //################## GPIO-configuration ##############################
    // Please note: GPIOs 34, 35, 36, 39 are input-only and don't have pullup-resistors.
    // So if connecting a button to these, make sure to add a 10k-pullup-resistor for each button.
    // Further infos: https://randomnerdtutorials.com/esp32-pinout-reference-gpios/
    #ifdef SD_MMC_1BIT_MODE
        // uSD-card-reader (via SD-MMC 1Bit)
        //
        // SD_MMC uses fixed pins
        //  (MOSI)    15  CMD
        //  (SCK)     14  SCK
        //  (MISO)     2  D0
    #else
        // uSD-card-reader (via SPI)
        #define SPISD_CS                    15          // GPIO for chip select (SD)
        #ifndef SINGLE_SPI_ENABLE
            #define SPISD_MOSI              13          // GPIO for master out slave in (SD) => not necessary for single-SPI
            #define SPISD_MISO              16          // GPIO for master in slave ou (SD) => not necessary for single-SPI
            #define SPISD_SCK               14          // GPIO for clock-signal (SD) => not necessary for single-SPI
        #endif
    #endif

    #ifdef RFID_READER_TYPE_PN5180
        #define RFID_BUSY                   16          // PN5180 BUSY PIN
        #define RFID_RST                    22          // PN5180 RESET PIN
        #define RFID_IRQ                    39          // PN5180 IRQ PIN (only needed for low power card detection)
    #else
        #define RFID_RST                    99           //Olny need for MRFC522 I2C but has to be set anyway; so let's use a dummy-number
        
        #ifdef RFID_READER_TYPE_MFRC522_SPI
            // RFID (via SPI)
            #define RFID_CS                 21          // GPIO for chip select (RFID)
            #define RFID_MOSI               23          // GPIO for master out slave in (RFID)
            #define RFID_MISO               19          // GPIO for master in slave out (RFID)
            #define RFID_SCK                18          // GPIO for clock-signal (RFID)
        #endif
    #endif

    // I2S (DAC)
    #define I2S_DOUT                        25          // Digital out (I2S)
    #define I2S_BCLK                        27          // BCLK (I2S)
    #define I2S_LRC                         26          // LRC (I2S)

    // Rotary encoder
    #ifdef USEROTARY_ENABLE
        //#define REVERSE_ROTARY                        // To reverse encoder's direction; switching CLK / DT in hardware does the same
        #define ROTARYENCODER_CLK           34          // rotary encoder's CLK
        #define ROTARYENCODER_DT            35          // Info: Lolin D32 / Lolin D32 pro 35 are using 35 for battery-voltage-monitoring!
    #endif

    // Amp enable (optional)
    //#define GPIO_PA_EN                      112         // To enable amp for loudspeaker (GPIO or port-channel)
    //#define GPIO_HP_EN                      113         // To enable amp for headphones (GPIO or port-channel)

    // Control-buttons (set to 99 to DISABLE; 0->39 for GPIO; 100->115 for port-expander)
    #define NEXT_BUTTON                      4          // Button 0: GPIO to detect next
    #define PREVIOUS_BUTTON                  2          // Button 1: GPIO to detect previous (Important: as of 19.11.2020 changed from 33 to 2; make sure to change in SD-MMC-mode)
    #define PAUSEPLAY_BUTTON                 0          // Button 2: GPIO to detect pause/play
    #define ROTARYENCODER_BUTTON            32          // (set to 99 to disable; 0->39 for GPIO; 100->115 for port-expander)
    #define BUTTON_4                        99          // Button 4: unnamed optional button
    #define BUTTON_5                        99          // Button 5: unnamed optional button

    //#define BUTTONS_LED                   114         // Powers the LEDs of the buttons. Make sure the current consumed by the LEDs can be handled by the used GPIO

    // Channels of port-expander can be read cyclic or interrupt-driven. It's strongly recommended to use the interrupt-way!
    // Infos: https://forum.espuino.de/t/einsatz-des-port-expanders-pca9555/306
    #ifdef PORT_EXPANDER_ENABLE
        #define PE_INTERRUPT_PIN            99          // GPIO that is used to receive interrupts from port-expander
    #endif

    // I2C-configuration (necessary for RC522 [only via i2c - not spi!] or port-expander)
    #ifdef I2C_2_ENABLE
        #define ext_IIC_CLK                 4           // i2c-SCL (clock)
        #define ext_IIC_DATA                2           // i2c-SDA (data)
    #endif
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

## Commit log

2021-02-04 Setting for use of longpress buttons for Volume
2021-02-14 Custom Button Layouts
2021-02-14 5 Buttons , Build errors
    [main.cpp, settings-custom.h, settings-espa1s.h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]
2021-02-14 Check Buttons Enabled
2021-02-15 Control buttons for Web UI
2021-02-17 New Multi Button System
2021-02-22 PCB QUino Dogbox
    [AudioAMP.sch, LiPoPower.sch, QUino-Dogbox.kicad_pcb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]
2021-02-23 Schaltplan pdf
    [LiPoPower.sch, QUino-Dogbox.sch, SWITCHED_3V3.sch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]
2021-02-26 Update ESP32 to WROVER-B
    [AudioAMP.sch, LiPoPower.sch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]
2024-12-16 Check if Power Defined
2024-12-16 RFID I2C Compile Error
    [RfidMfrc522.cpp, settings-complete.h, settings-custom.h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]
2024-12-18 Angabe der DL-Filenames
2024-12-28 ArduinoJson 7
2025-01-02 Complete PCB
    [Audio.kicad_sch, LiPoCharger.kicad_sch, QUinoComplete.kicad_pcb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]
